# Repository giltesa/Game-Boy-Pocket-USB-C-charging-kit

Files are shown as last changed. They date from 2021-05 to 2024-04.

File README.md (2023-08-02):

# Game Boy Pocket USB-C Charging Kit

( This project is a fork from my Game Boy Color USB-C Charging Kit )

The **Game Boy Pocket USB-C Charging Kit** is a circuit that allows you to charge a **Nintendo Game Boy Pocket** by **USB-C** and use a **Li-ion** battery instead of AA batteries.

This circuit includes the famous **TP4056** and **DW01A**. The first one is the device in charge of charging the battery, and the second one is protecting the lifetime of the battery of the over-discharge.

This kit includes two boards. If you want to install it easy, it's enough with the main board which doesn't need any cable for working. However, if you want to have the status LEDs in the same place as the original status LED, then you will need to solder the second board and joint both with 3 cables. You can choose the best option for you.

This kit contains 3 boards:

- USB-C board
- Main board
- LEDs board

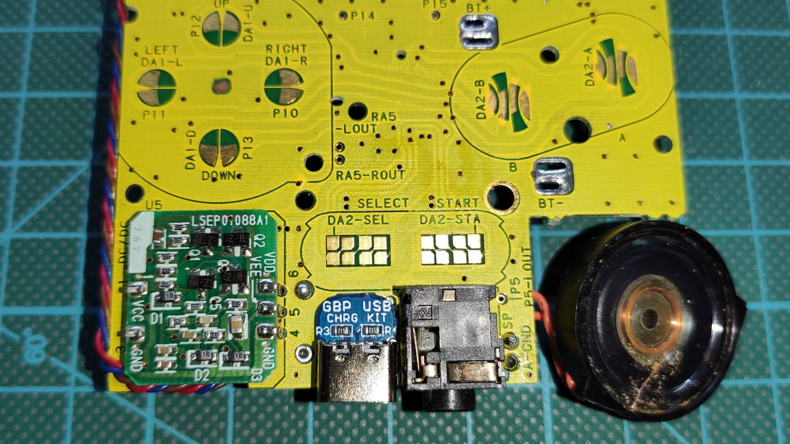
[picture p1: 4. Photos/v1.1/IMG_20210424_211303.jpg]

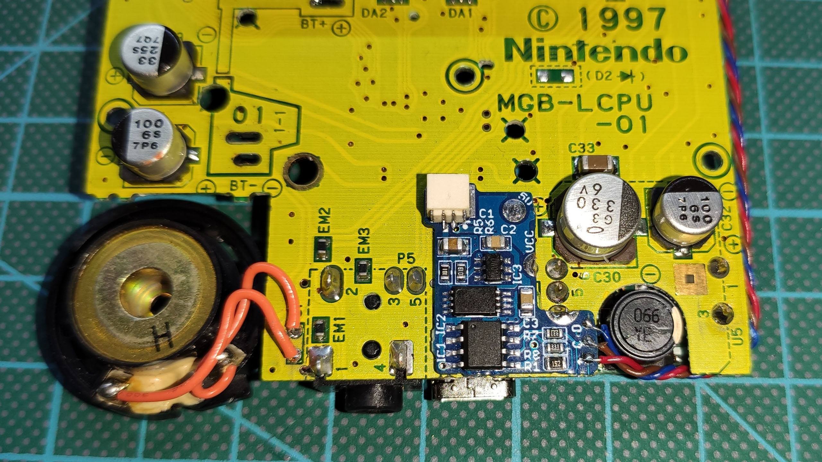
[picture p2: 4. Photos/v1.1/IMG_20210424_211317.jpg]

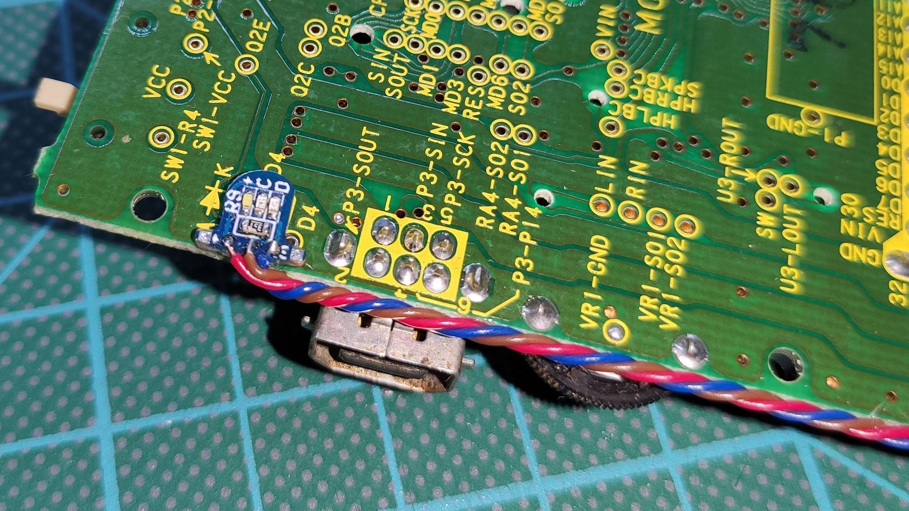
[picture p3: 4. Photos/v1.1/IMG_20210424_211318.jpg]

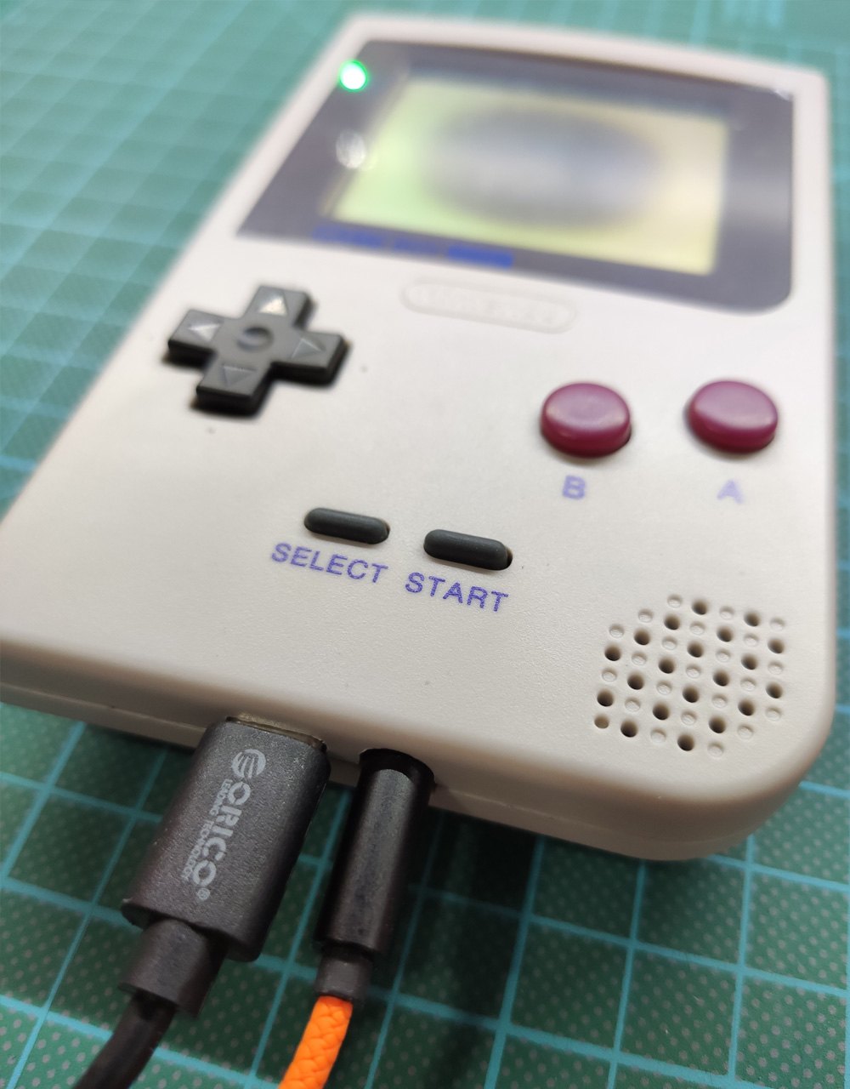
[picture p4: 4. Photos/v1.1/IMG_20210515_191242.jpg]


## Youtube:

Game Boy Pocket USB-C Charging Kit (Installation)

GBP (https://www.youtube.com/watch?v=yOIhhSY7Itc)

## Would you like it?

https://shop.giltesa.com/product/game-boy-pocket-usb-c-charging-kit/

## More

- [giltesa.com](https://giltesa.com "giltesa.com")
- [twitter.com](https://twitter.com/giltesa "twitter.com")

## License

This project is licensed under a **Creative Commons** license:
**[Attribution-NonCommercial-ShareAlike 4.0 International (CC BY-NC-SA 4.0) ](https://creativecommons.org/licenses/by-nc-sa/4.0/)**

Check the [LICENSE.md](LICENSE.md) for more information.

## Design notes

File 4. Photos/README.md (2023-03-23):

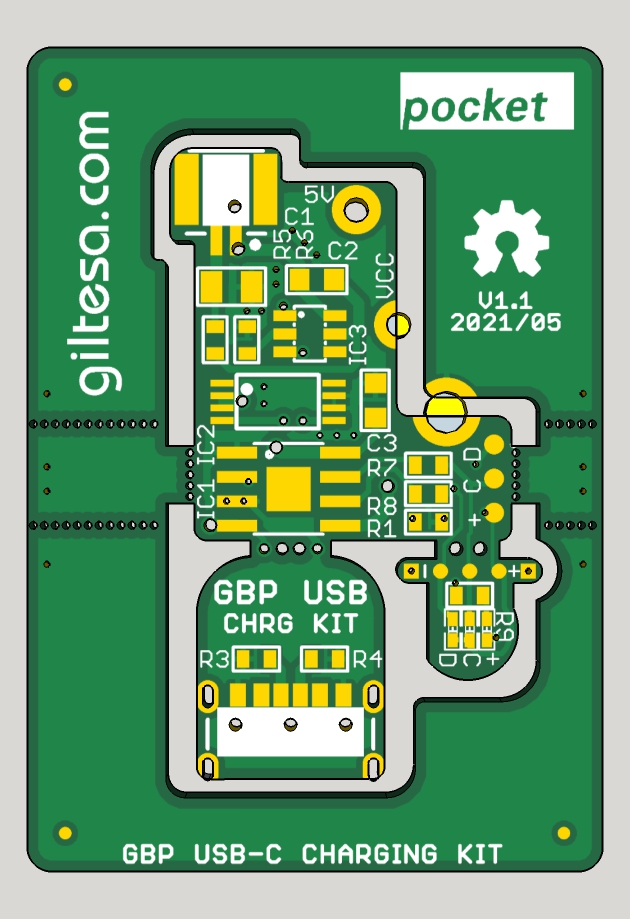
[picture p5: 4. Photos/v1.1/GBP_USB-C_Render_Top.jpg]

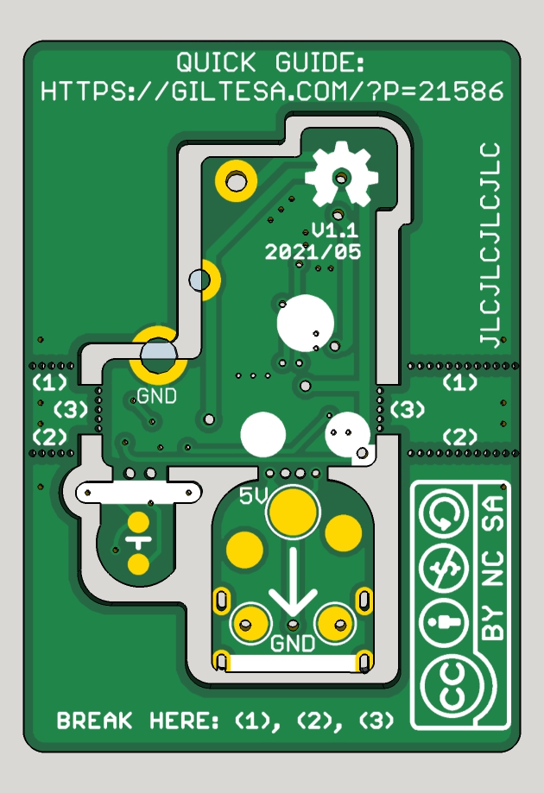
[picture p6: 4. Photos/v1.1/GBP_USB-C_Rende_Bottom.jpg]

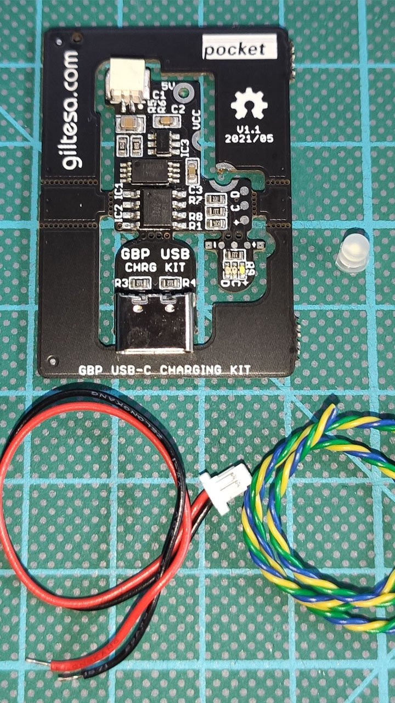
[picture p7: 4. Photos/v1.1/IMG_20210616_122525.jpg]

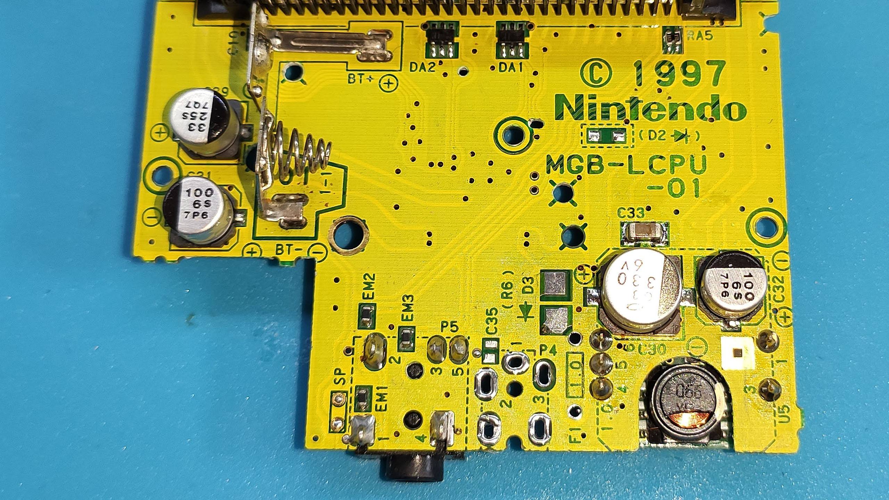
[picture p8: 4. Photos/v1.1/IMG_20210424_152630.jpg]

GBP
GBP
GBP
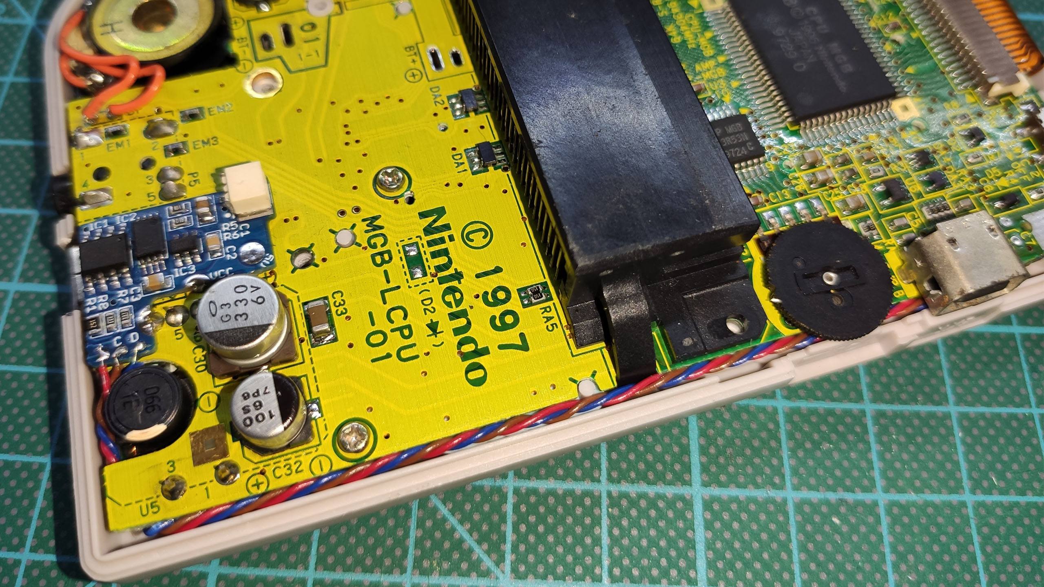
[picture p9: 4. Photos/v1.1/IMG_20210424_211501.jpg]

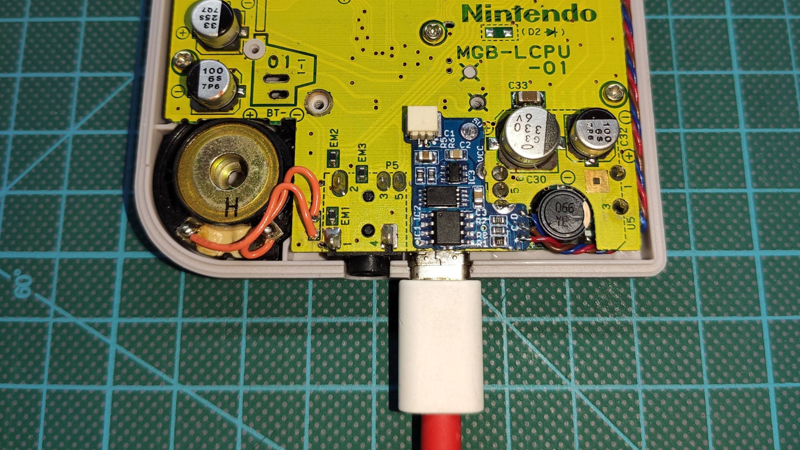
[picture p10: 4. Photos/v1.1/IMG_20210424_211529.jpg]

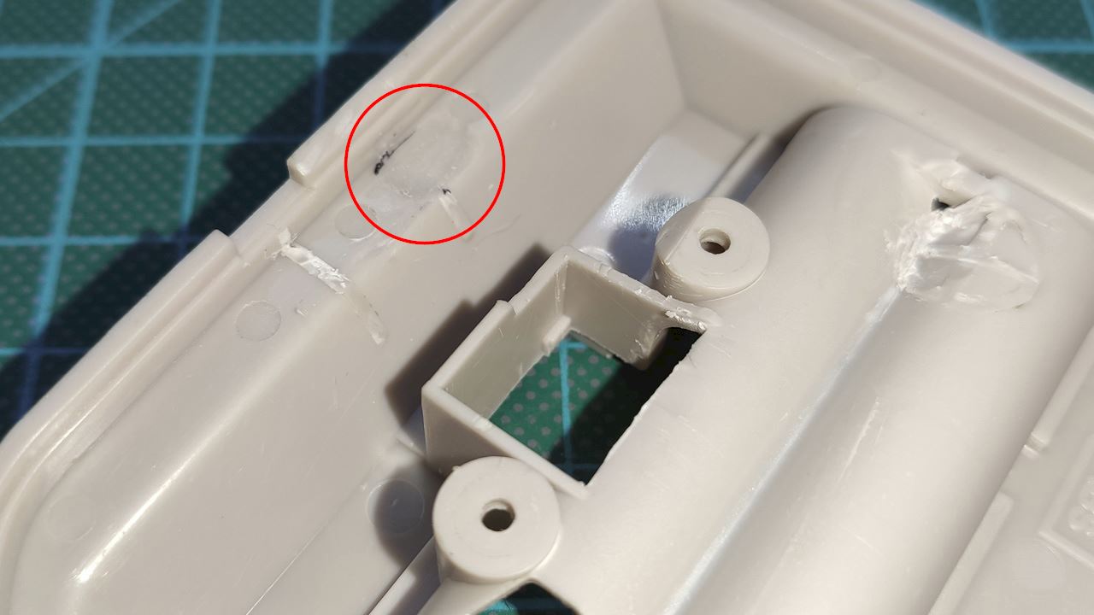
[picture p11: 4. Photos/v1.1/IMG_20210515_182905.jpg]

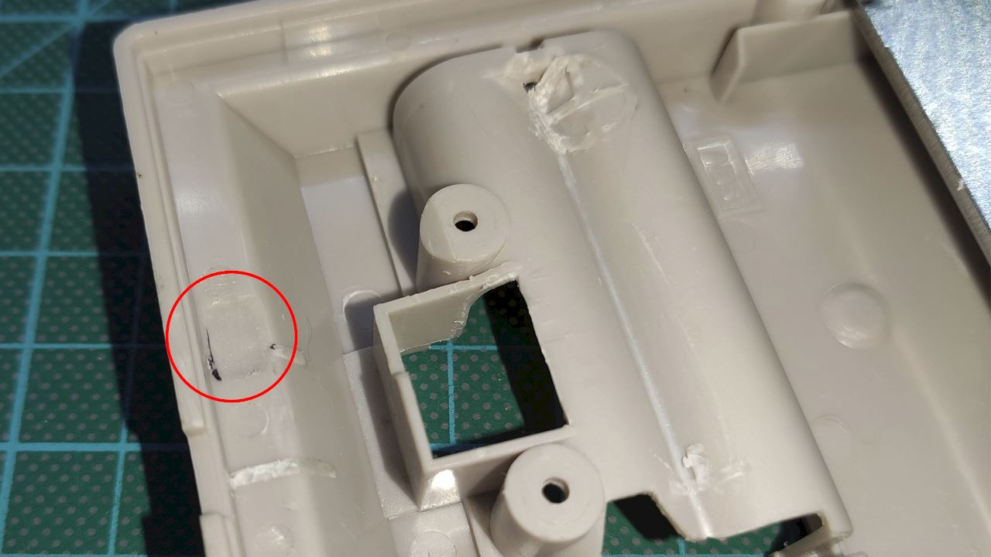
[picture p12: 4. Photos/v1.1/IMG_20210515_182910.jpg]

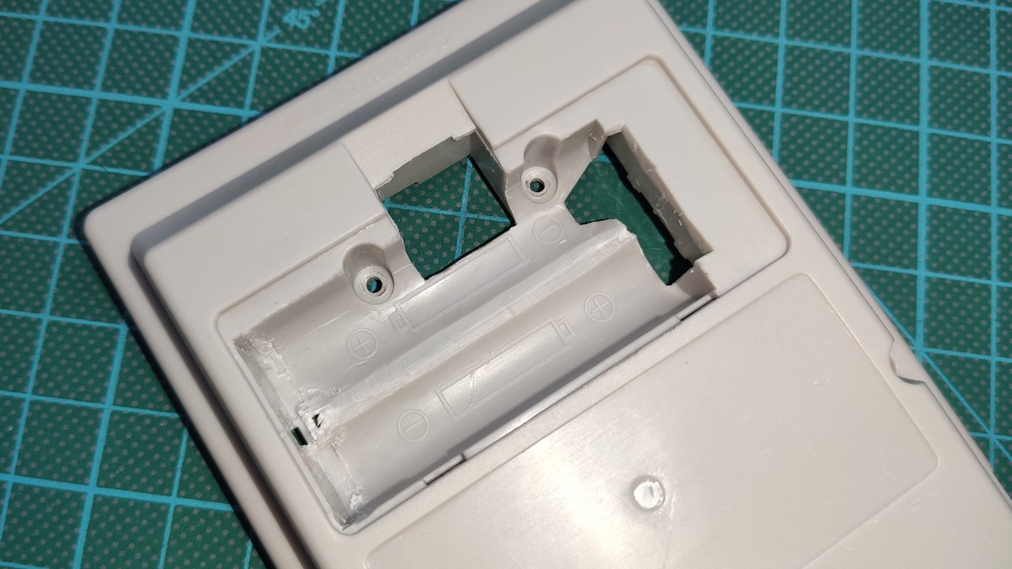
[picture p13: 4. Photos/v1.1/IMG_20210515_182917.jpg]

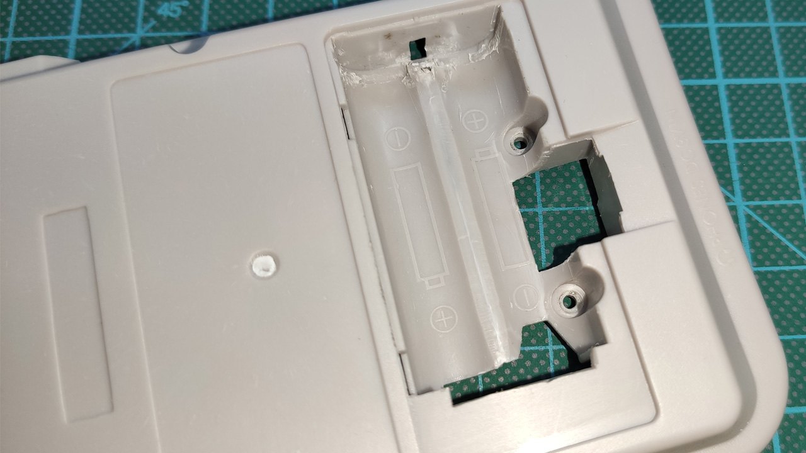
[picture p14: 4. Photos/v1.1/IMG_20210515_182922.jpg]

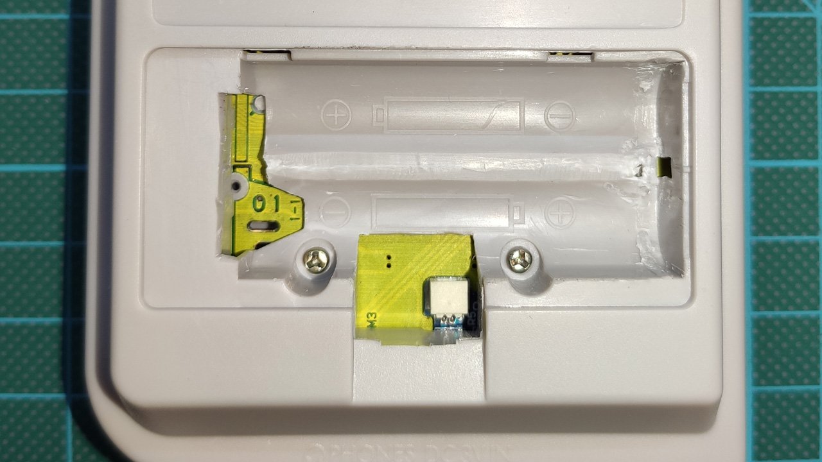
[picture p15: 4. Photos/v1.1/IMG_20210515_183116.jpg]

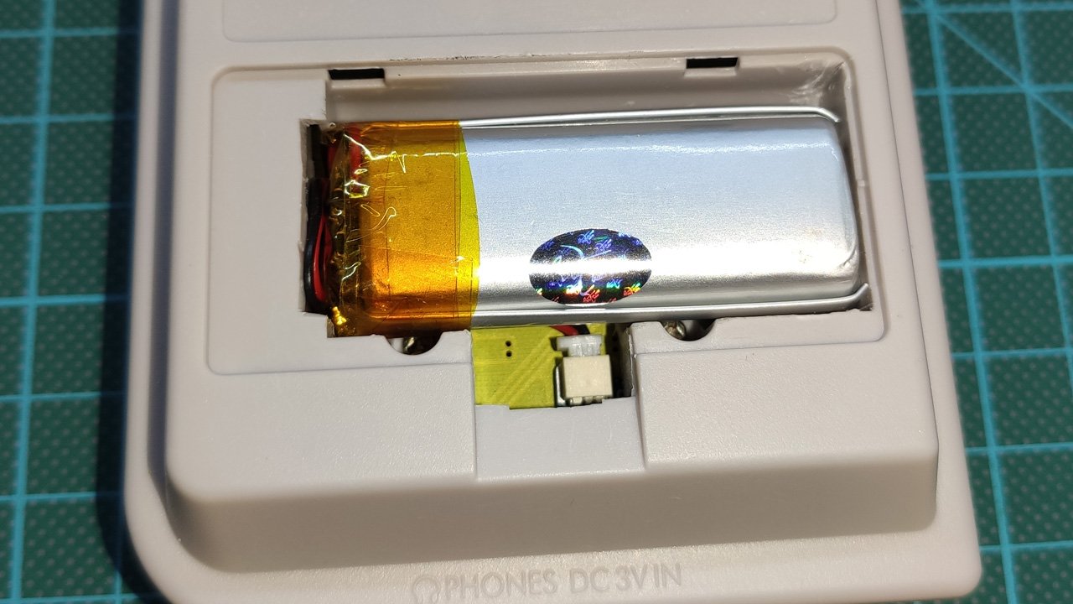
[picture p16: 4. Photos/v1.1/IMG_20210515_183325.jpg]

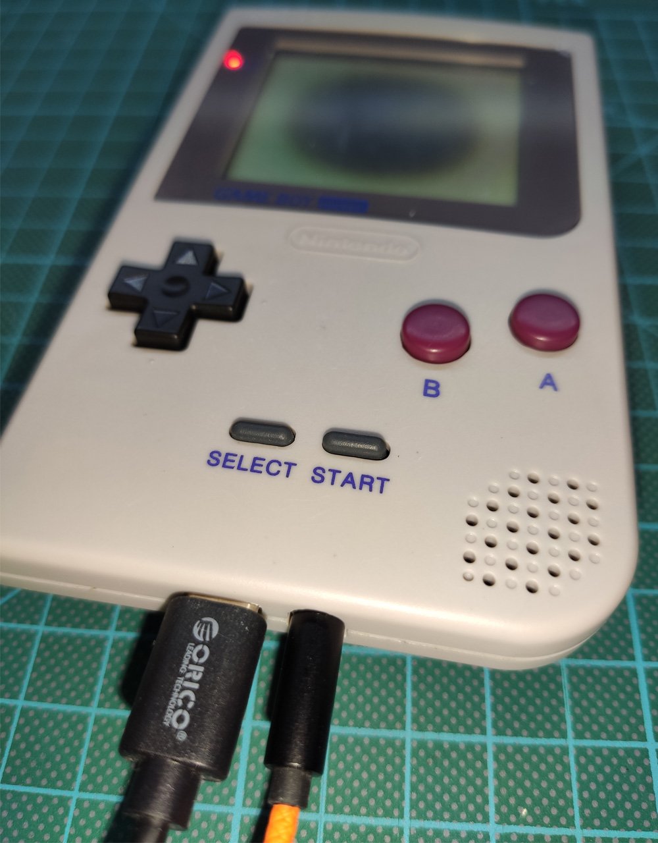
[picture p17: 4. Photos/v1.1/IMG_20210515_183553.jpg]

GBP

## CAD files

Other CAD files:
2. Renders, 3D models/GBP USB-C Charging Kit v1.2 frame.skp
2. Renders, 3D models/GBP USB-C Charging Kit v1.2.skp
2. Renders, 3D models/GBP USB-C Charging Kit v1.3.skp
2. Renders, 3D models/GBP USB-C Charging Kit v2.0 - Black.skp

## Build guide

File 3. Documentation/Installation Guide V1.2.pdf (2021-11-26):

# USB-C CHARGING KIT FOR GAME BOY POCKET

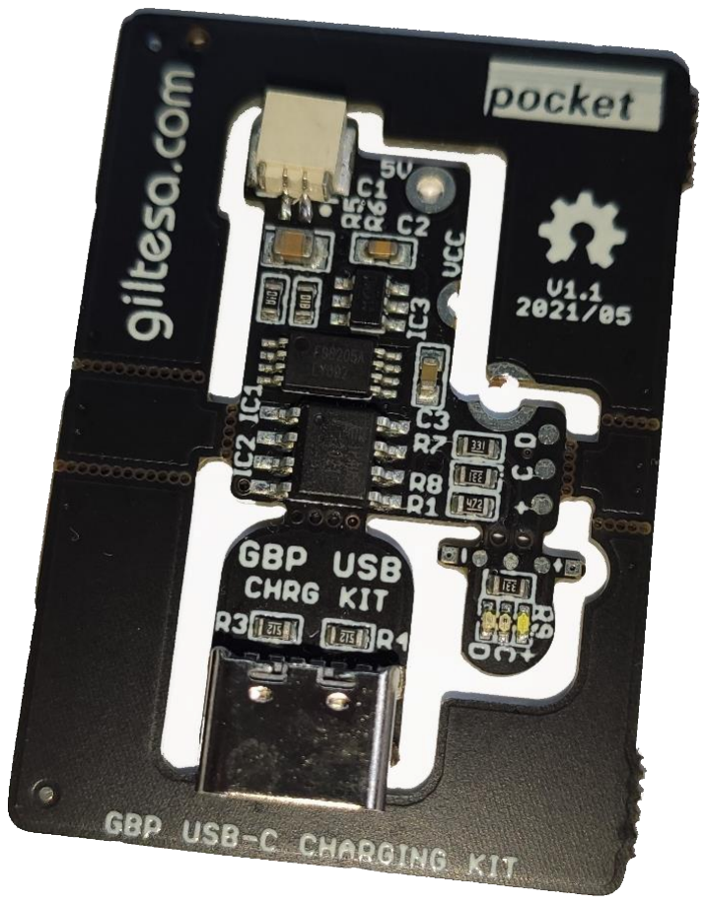
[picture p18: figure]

# VIDEO INSTALLATION

https://www.youtube.com/watch?v=yOIhhSY7Itc

# NINTENDO USB-C CHARGING KITS

https://giltesa.com/en/nintendo-usb-c-charging-kit

The Game Boy Pocket USB-C charging kit is a circuit that allows you to charge a Nintendo Game Boy Pocket by USB-C and use a Li-ion battery instead of AAA batteries.

This circuit includes the famous TP4056 and DW01A. The first one is the device in charge of charging the battery, and the second one is protecting the lifetime of the battery of the overdischarge.

Because the GBP board doesn’t have enough free space, you need to remove some components of your GBP board before the installation. These components are not necessary because this board replaces the AAA and jack powered.

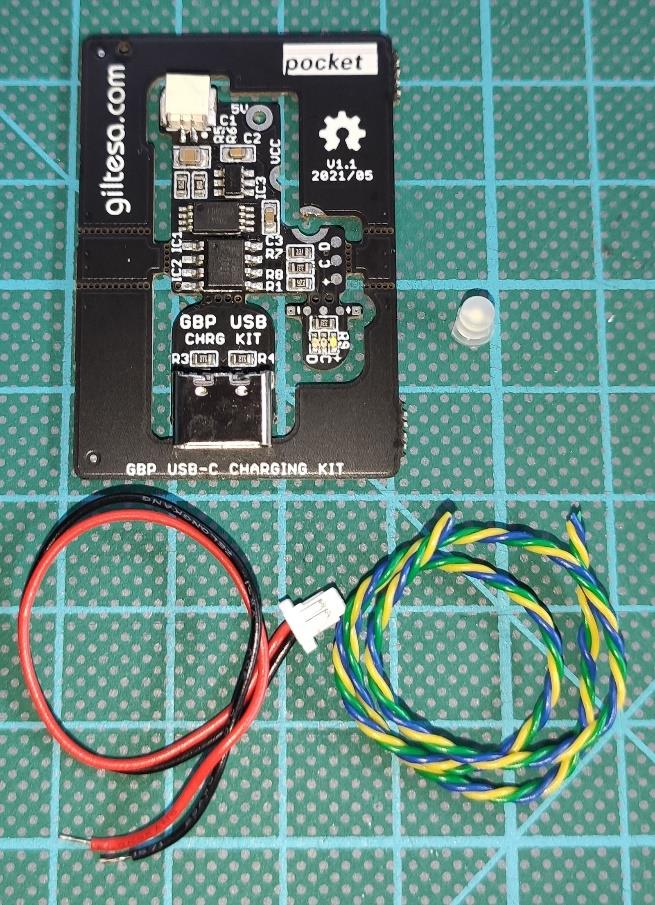
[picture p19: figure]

Included with this kit:

- Main board + USB-C board + LEDs board
- Light diffuser
- Li-ion battery cable
- Installation cable

Not included:

- Li-ion battery

Required tools:

- Screwdriver: + and Y
- Soldering iron
- Tin
- Flux
- Isopropyl alcohol
- Tweezers
- Cutter for cutting the case

This module has been designed to be used with the console's original voltage regulator because it supports an input voltage range between 2 a 4.6V and the battery kit provide a voltage between 2.75 a 4.2V. If you also want to change the original power supply, it’s important it is compatible with the voltage provided for the battery kit, otherwise you may damage something.

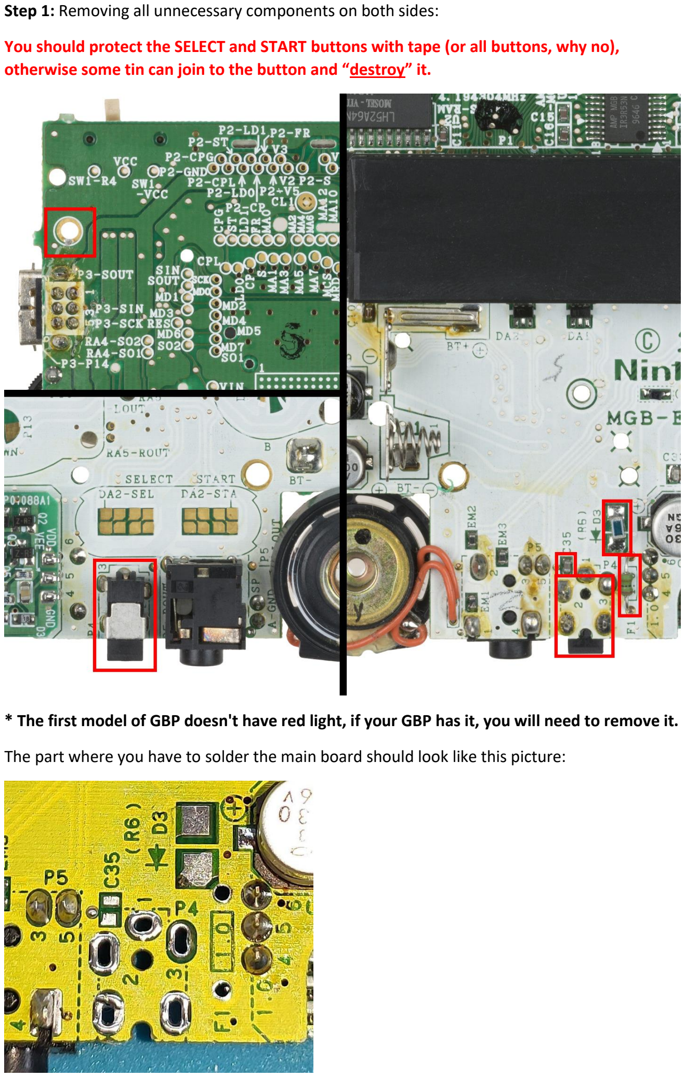
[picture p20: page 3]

Step 1: Removing all unnecessary components on both sides:

You should protect the SELECT and START buttons with tape (or all buttons, why no), otherwise some tin can join to the button and “destroy” it.

* The first model of GBP doesn't have red light, if your GBP has it, you will need to remove it.

The part where you have to solder the main board should look like this picture:

Step 2: The USB-C board must be the first board you have to solder. It is because the pads to solder it are in the opposite side of the jack and after you have finished to solder it the next board, main board, will hide the pads.

For soldering it, I recommend you pre-solder first the VCC pad and then, solder it to the GBP board and if you have centred it well, you can continue with the rest of the pads to hold it super strong.

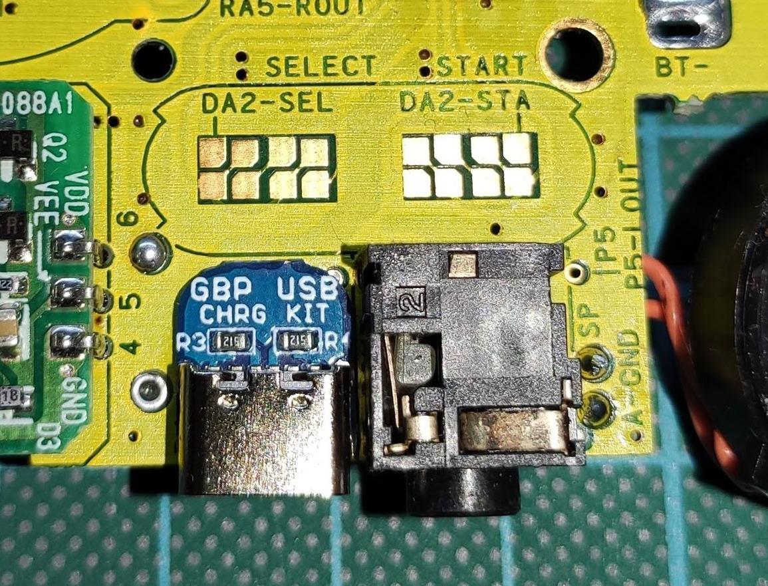
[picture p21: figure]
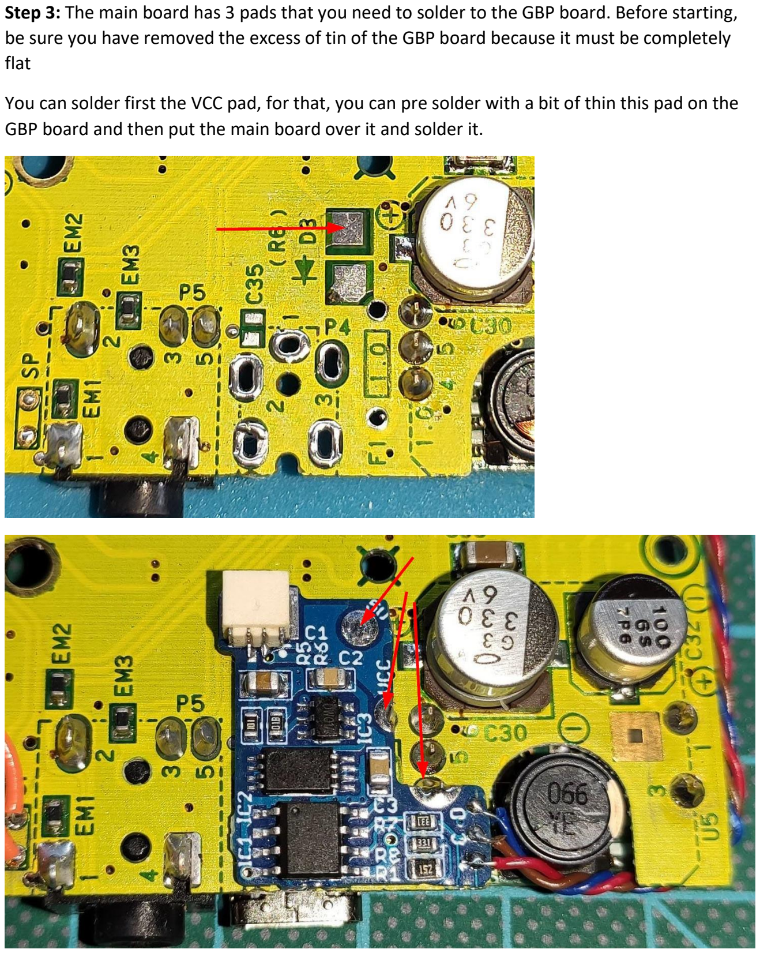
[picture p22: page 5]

Step 3: The main board has 3 pads that you need to solder to the GBP board. Before starting, be sure you have removed the excess of tin of the GBP board because it must be completely flat

You can solder first the VCC pad, for that, you can pre solder with a bit of thin this pad on the GBP board and then put the main board over it and solder it.

Step 4: Soldering the LEDs board. This board is as small as the original LED. This board has 2 pads on the bottom side and 5 more on the top side.

There are two possible ways to solder it, but one part is common:

Only for GBP with red light:

After removing the original red light, you can see two pads under where the LED was. You have to solder these two pads to the two pads on the bottom side of the light board.

You can pre-solder the pads on the bottom side of the light board and then, put the board in the correct place and hot the opposite side of the GBP board. You will see how the tin start to melt and join.

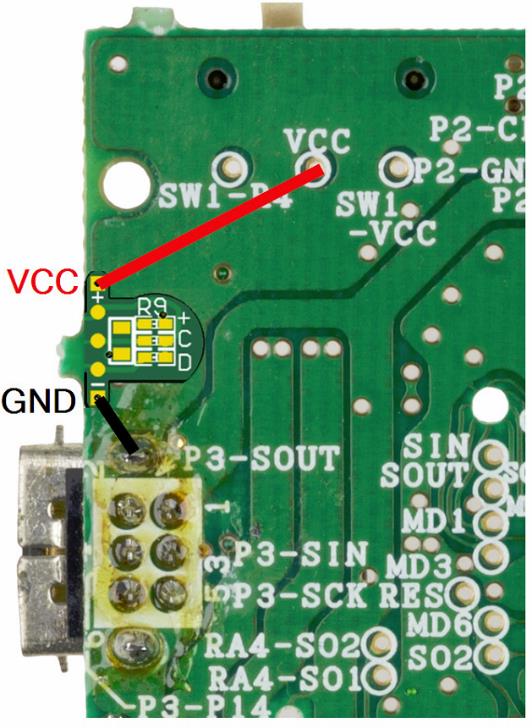
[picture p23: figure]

Only for GBP without red light:

Because this model doesn’t have light, you can install the light board in the same place as others GBP models.

First, you should put a bit of tape to protect the GBP and light board of short circuit. Put the tape on the big hole next to the EXT connector. You can use double side tape and use it to hold the light board to the GBP board.

After that, you can solder these two pins to the alternative points for getting these light indicator feature.

Common part:

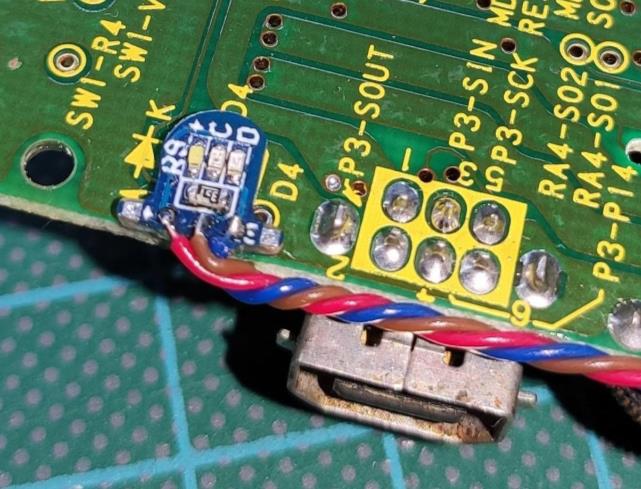
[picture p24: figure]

You can see the light board has 5 pads on the top side. You will need to solder the 3 pads in the centre to the main board.

Be sure, you join the pads with the correct pad of the main board.

- + to + (VCC)
- C to C (CHARGE)
- D to D (DONE)

## Extra information

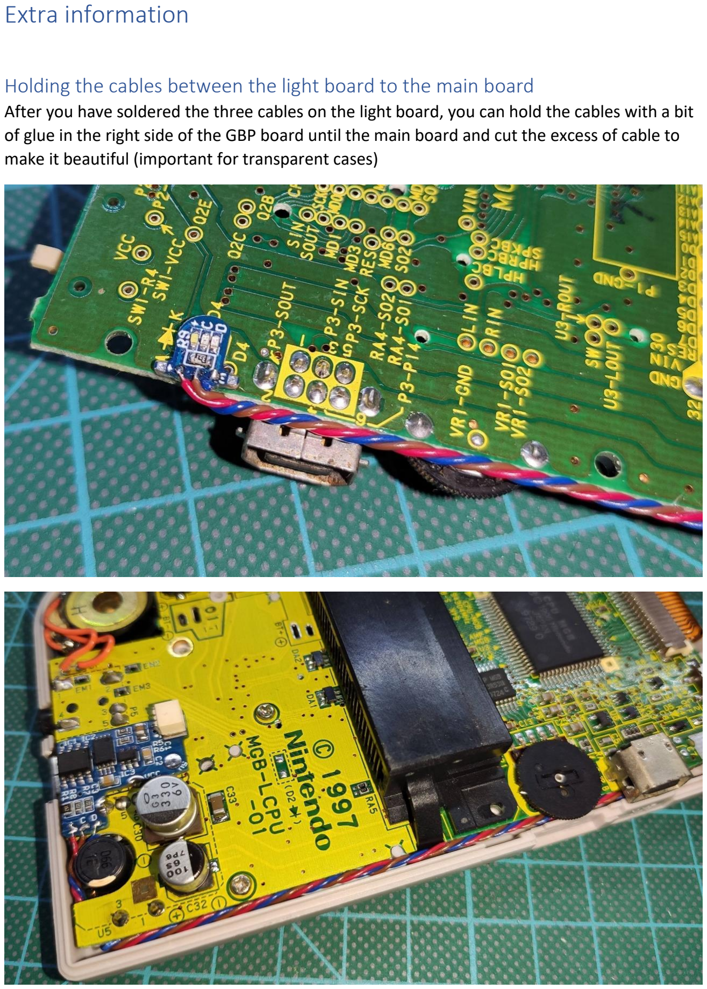
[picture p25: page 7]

### Holding the cables between the light board to the main board

After you have soldered the three cables on the light board, you can hold the cables with a bit of glue in the right side of the GBP board until the main board and cut the excess of cable to make it beautiful (important for transparent cases)

### LED diffuser

The kit includes a LED diffuser. It is a simple 3mm LED without legs that help the light board to focus the light to the centre.

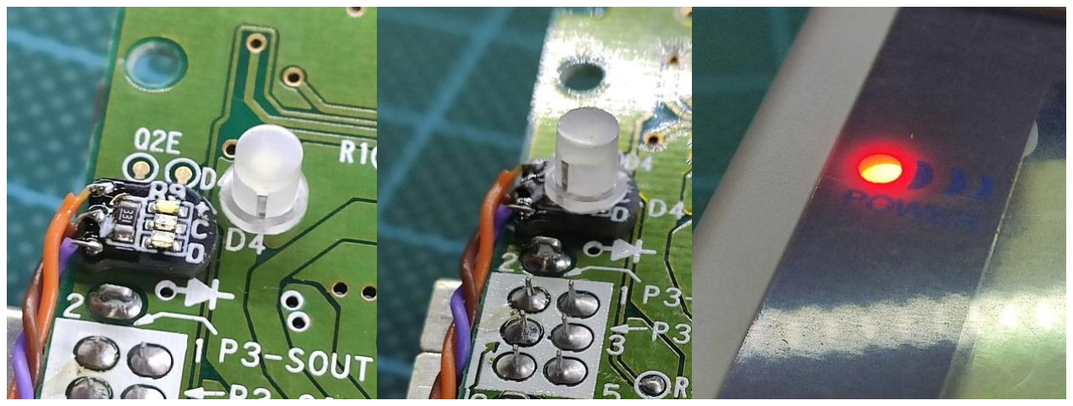
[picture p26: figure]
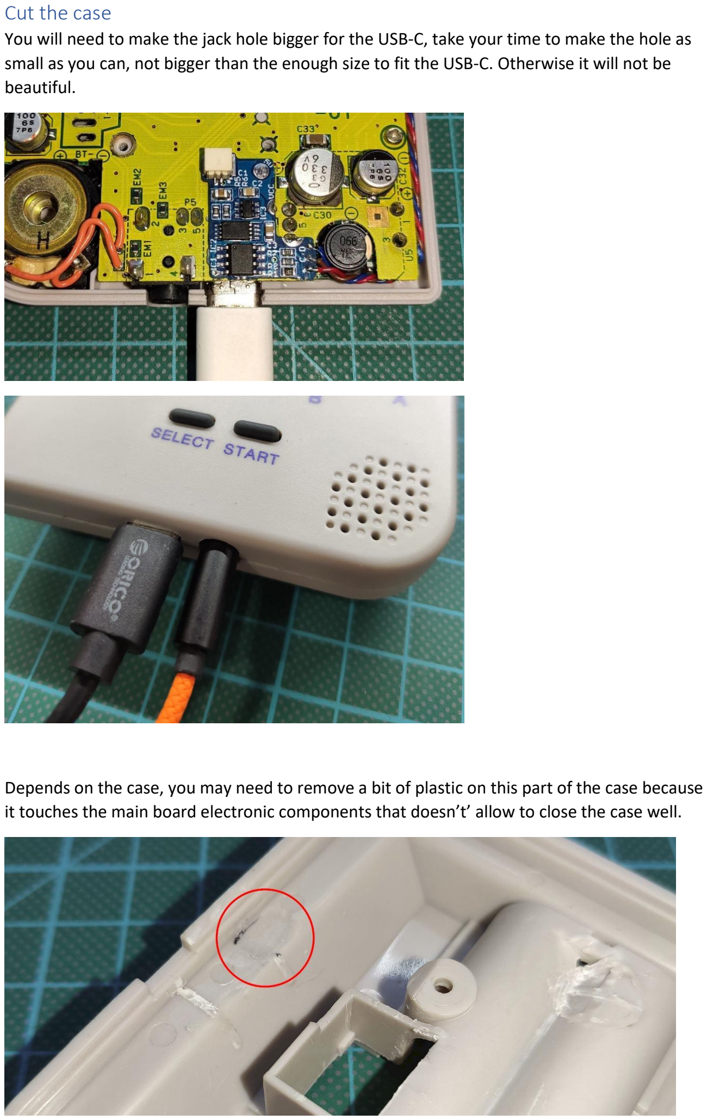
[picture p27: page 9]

### Cut the case

You will need to make the jack hole bigger for the USB-C, take your time to make the hole as small as you can, not bigger than the enough size to fit the USB-C. Otherwise it will not be beautiful.

Depends on the case, you may need to remove a bit of plastic on this part of the case because it touches the main board electronic components that doesn’t’ allow to close the case well.

### Battery

You can put the battery as big as you can find, in my case cutting the case as you can see in these pictures, I was able to put a 1500mAh battery.

Inside the documentation folder on the GitHub you can find information about the battery:

https://github.com/giltesa/Game-Boy-Pocket-USB-C-chargingkit/tree/master/3.%20Documentation/Battery (https://github.com/giltesa/Game-Boy-Pocket-USB-C-charging-kit/tree/master/3.%20Documentation/Battery)

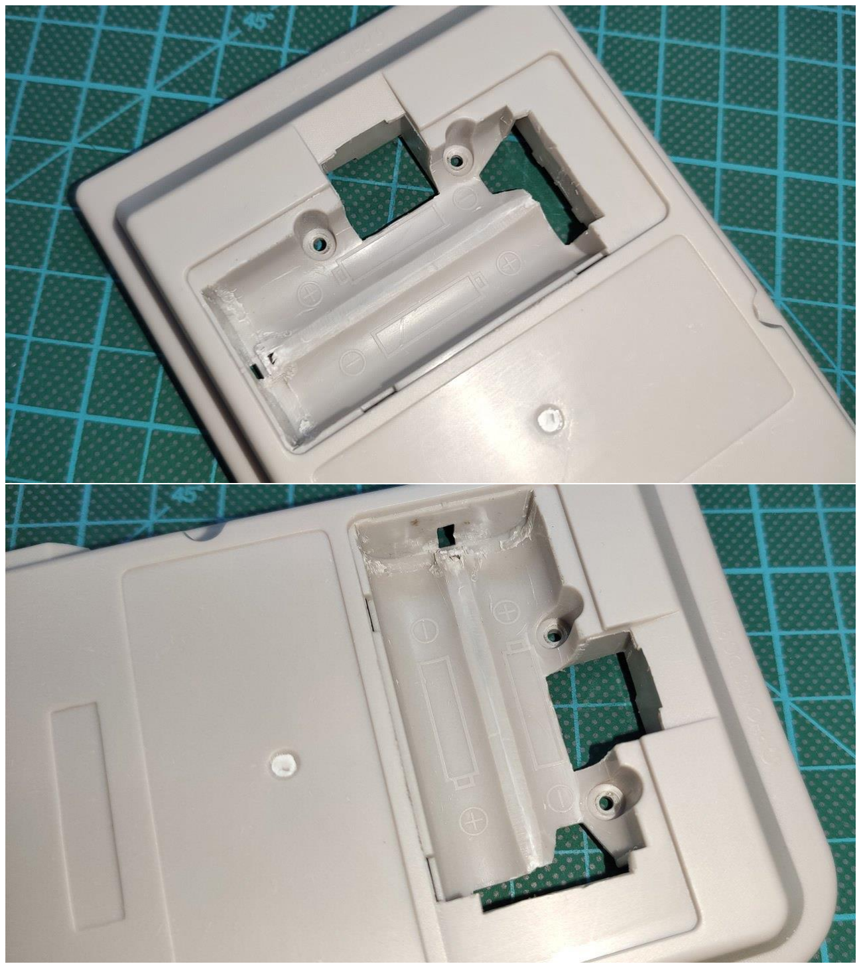
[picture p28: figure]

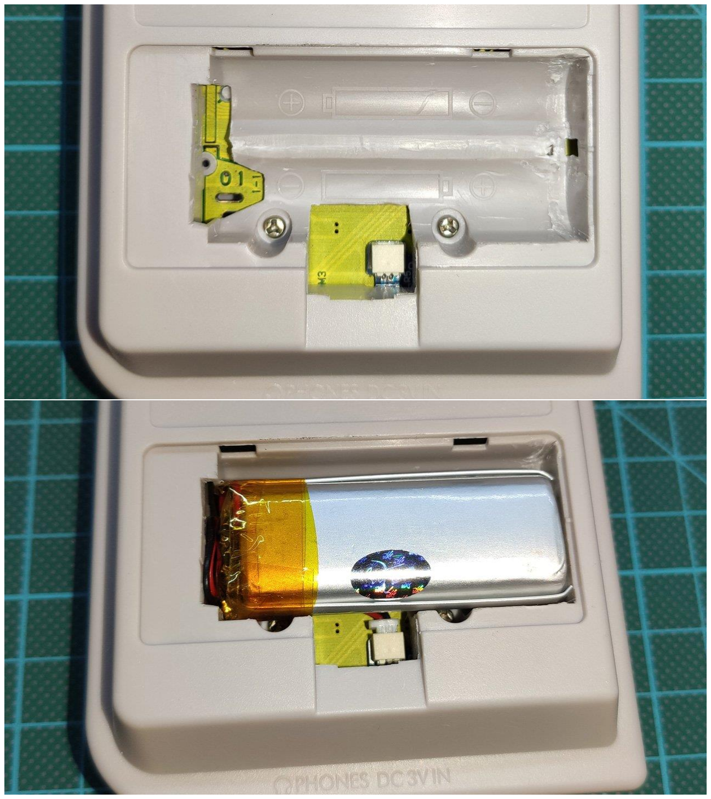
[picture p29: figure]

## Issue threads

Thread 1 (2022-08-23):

help with MGB-CPU-01 instructions

aparrish, 2022-08-23:
Hi! I'm trying to install the mod on a MGB-CPU-01 board. The [instructions in the Documentation directory](https://github.com/giltesa/Game-Boy-Pocket-USB-C-charging-kit/blob/master/3.%20Documentation/Incompatibility%20MGB-CPU-01.pdf) are a bit unclear to me. Could you maybe rephrase or rewrite the instructions? As currently written, it seems to me as though steps 1 and 2 are contradictory. Step 1 says to cover both pads with kapton tape, but then step 2 says that you should solder one of the pads... which would be covered with kapton tape at that point, if you followed step 1.

It seems like what I should be doing is soldering a bodge wire from the upper pad of D2 to pin 1 of the DC jack connector, and then covering the lower pad of D2 with kapton tape, along with the bodge wire, but leaving the upper pad of D2 exposed. Is that the case, or is it something else?

giltesa, 2022-08-24:
Hello Allison,

Sorry, yes, it was a bit confusing. I updated the pdf, I hope it is easier
to understand now:
https://github.com/giltesa/Game-Boy-Pocket-USB-C-charging-kit/blob/master/3.%20Documentation/Incompatibility%20MGB-CPU-01.pdf

[image: imagen.png]

Kind regards,
Alberto

El mié, 24 ago 2022 a las 1:54, Allison Parrish ***@***.***>)
escribió:

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

aparrish, 2022-08-24:
Ah okay, I get it! So the goal is to connect the 5V pad on the USB-C board to pin 1 of the DC jack, and to make sure that nothing gets accidentally soldered to either of the D2 pads. Thanks!

Closed 2022-08-24.

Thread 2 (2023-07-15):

biggest battery possible?

szechp, 2023-07-15:
Not an issue but a question:

If I cut down my shell to completely remove the battery compartments plastic, what's the biggest battery I can fit in there? I wouldnt mind if the battery is on the PCB, with only some tape between them.

giltesa, 2023-07-15:
Hello Philipp,

I was able to install a [1500mAh ](https://www.aliexpress.com/item/4000036271843.html) battery in a not trimmed battery compartment. If the compartment is ready for li-ion batteries, then it's possible to install a [1800mAh](https://www.aliexpress.com/item/1005001308043027.html) battery.

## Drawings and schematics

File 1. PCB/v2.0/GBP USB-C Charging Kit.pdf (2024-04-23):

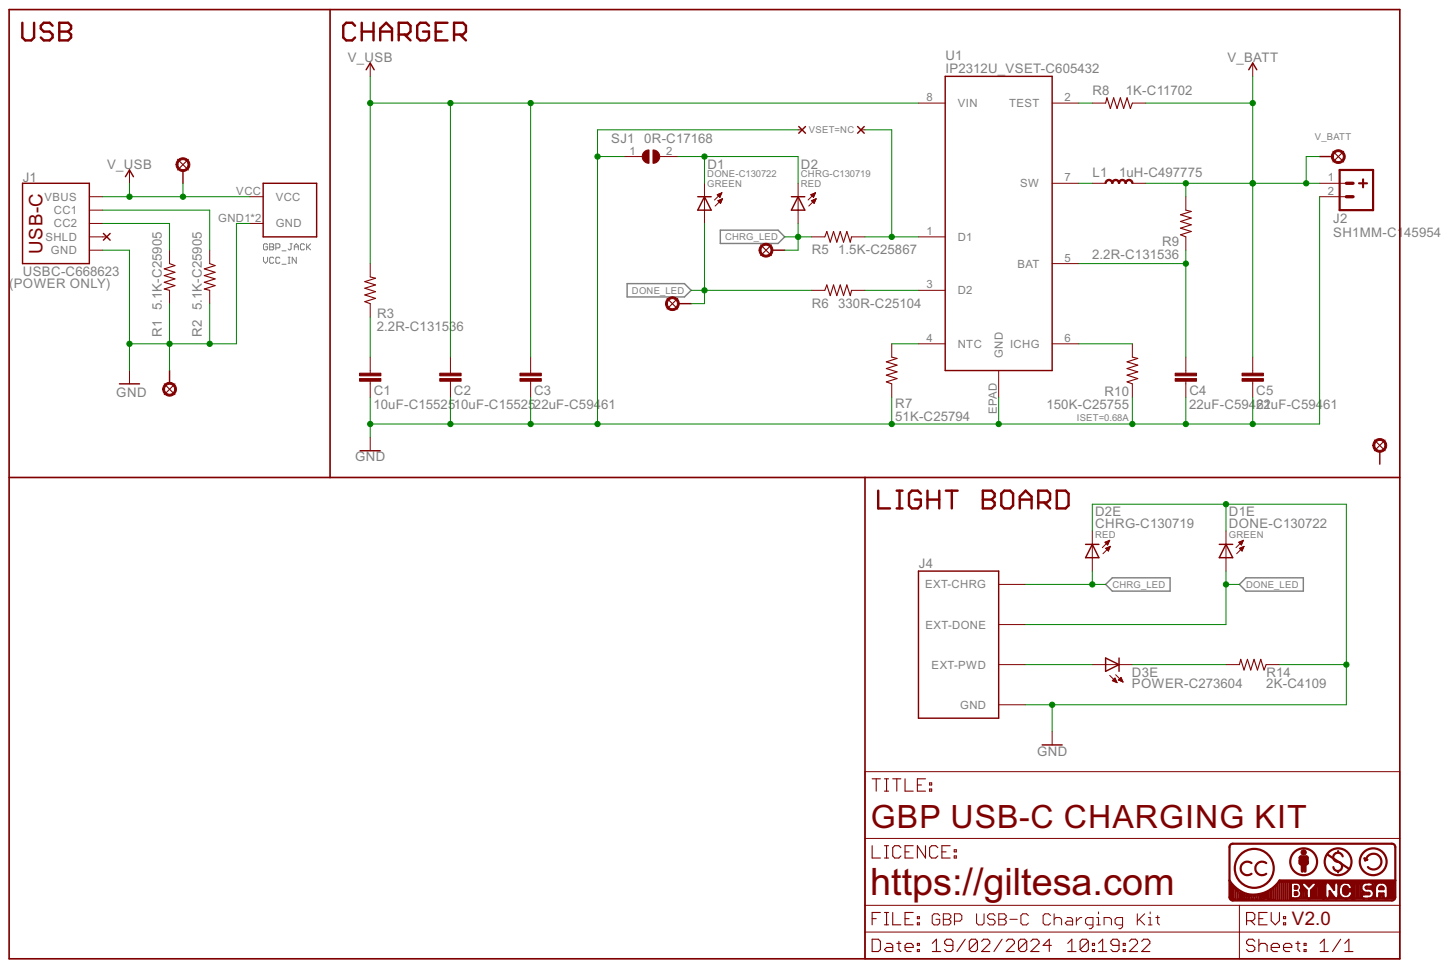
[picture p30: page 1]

GBP USB-C CHARGING KIT
https://giltesa.com

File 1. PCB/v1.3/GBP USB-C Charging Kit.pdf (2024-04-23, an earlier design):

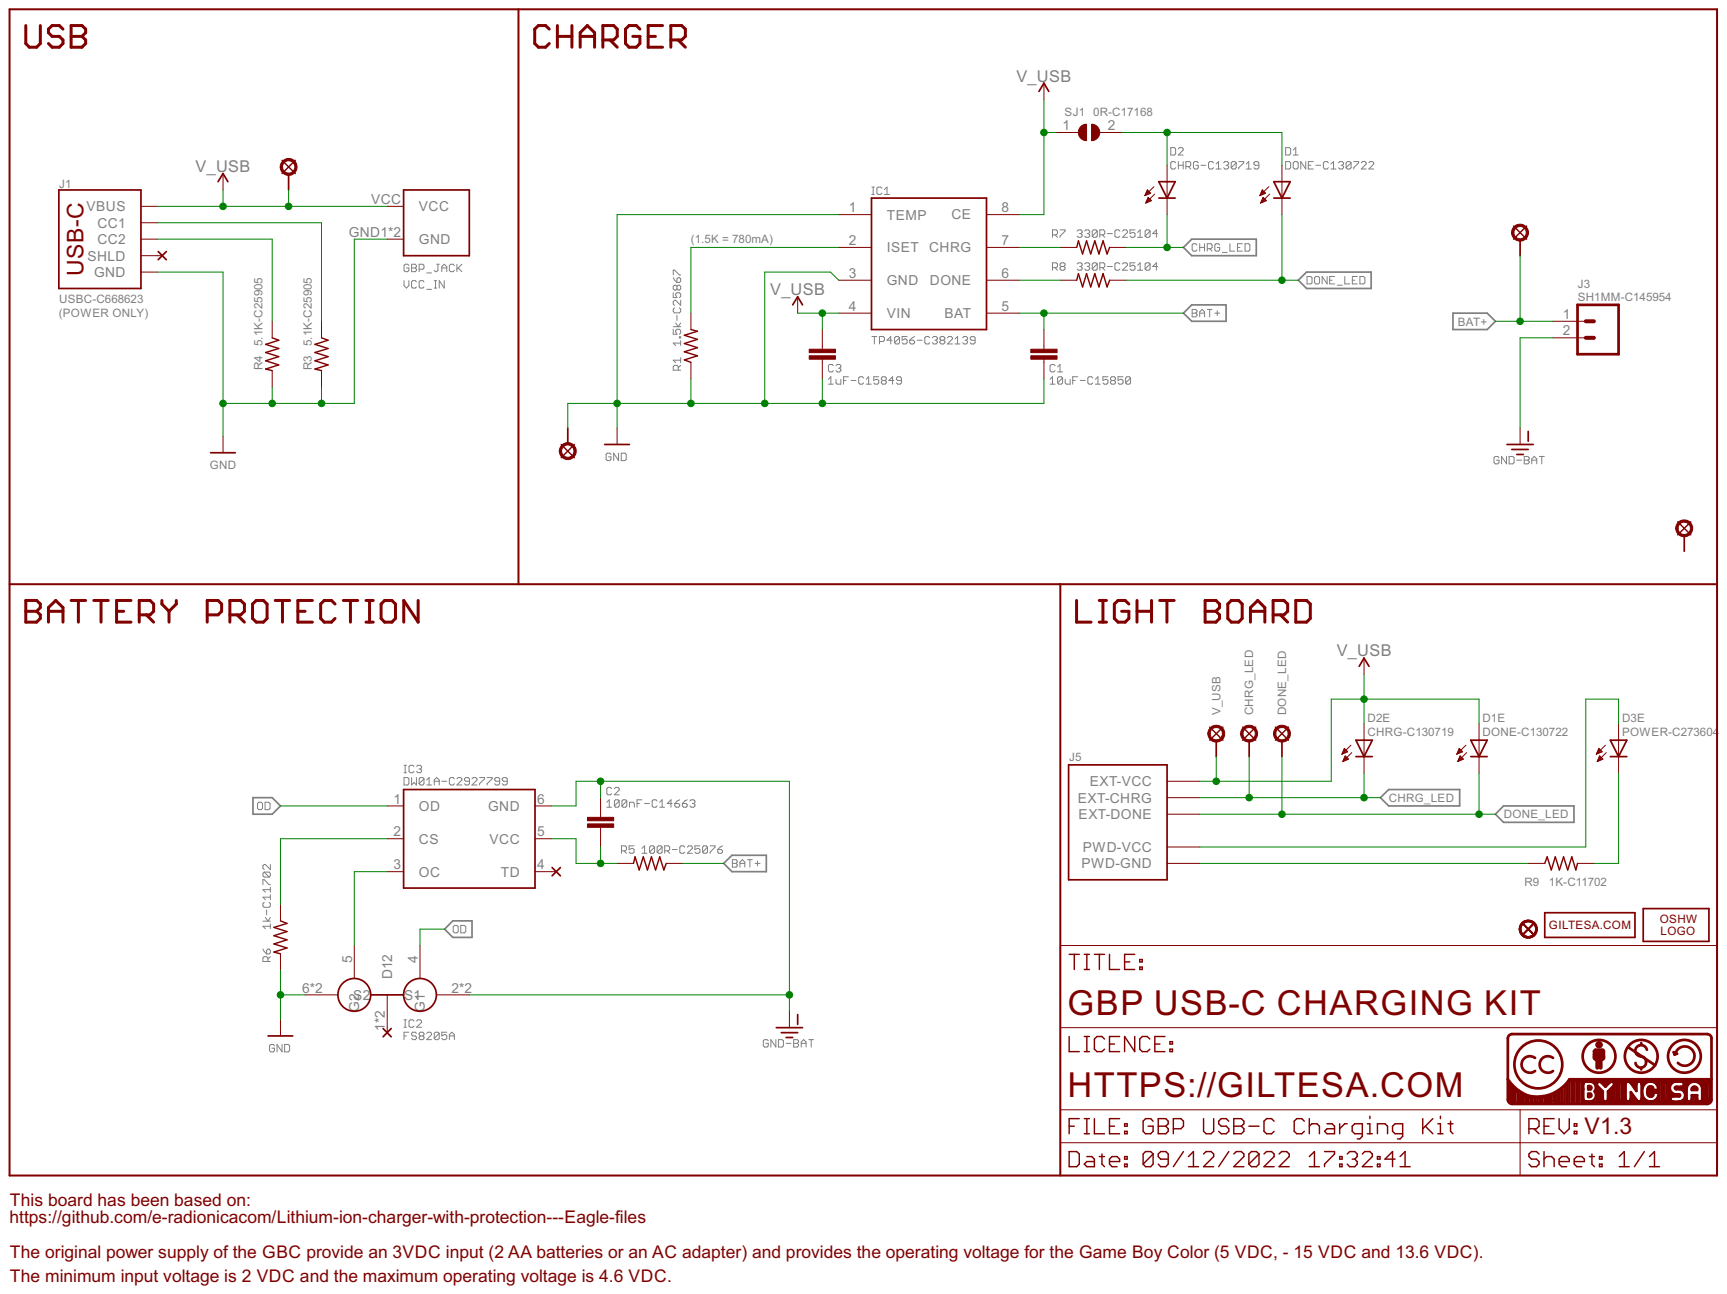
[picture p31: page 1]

GBP USB-C CHARGING KIT

https://github.com/e-radionicacom/Lithium-ion-charger-with-protection---Eagle-files This board has been based on: The original power supply of the GBC provide an 3VDC input (2 AA batteries or an AC adapter) and provides the operating voltage for the Game Boy Color (5 VDC, - 15 VDC and 13.6 VDC). The minimum input voltage is 2 VDC and the maximum operating voltage is 4.6 VDC.

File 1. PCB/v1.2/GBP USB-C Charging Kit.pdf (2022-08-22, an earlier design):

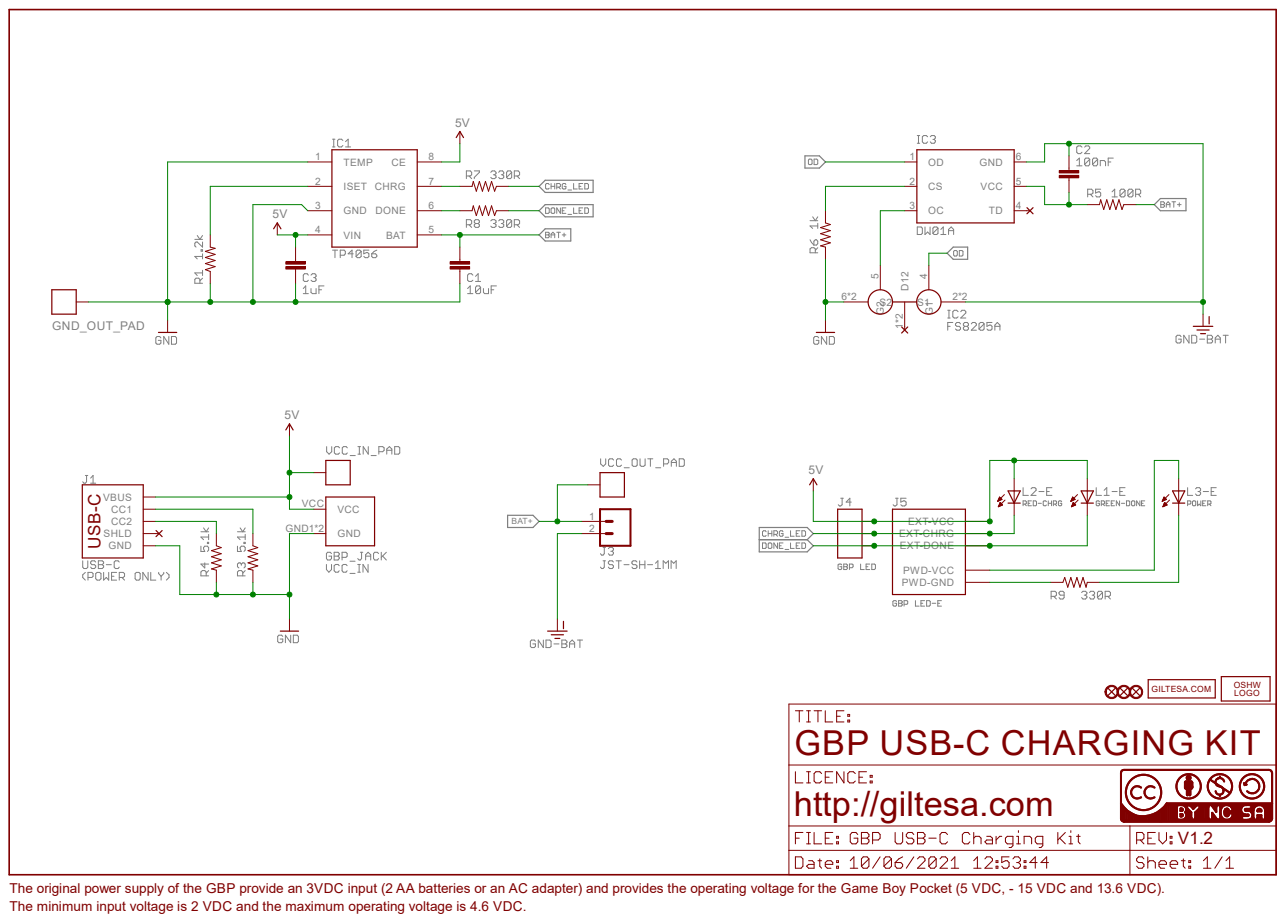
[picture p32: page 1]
TEMP 1; ISET 2; GND 3; VIN 4; BAT; DONE; CHRG; VCC; GND; VBUS CC1 CC2 SHLD; PWD-GND; PWD-VCC; EXT-CHRG EXT-DONE; EXT-VCC 1 2 GND GND1*2; VCC VCC GND_OUT_PAD; BAT+; GBP USB-C CHARGING KIT; OSHW

The minimum input voltage is 2 VDC and the maximum operating voltage is 4.6 VDC. USB⁻C

LOGO GILTESA.COM

http://giltesa.com

The original power supply of the GBP provide an 3VDC input (2 AA batteries or an AC adapter) and provides the operating voltage for the Game Boy Pocket (5 VDC, - 15 VDC and 13.6 VDC).

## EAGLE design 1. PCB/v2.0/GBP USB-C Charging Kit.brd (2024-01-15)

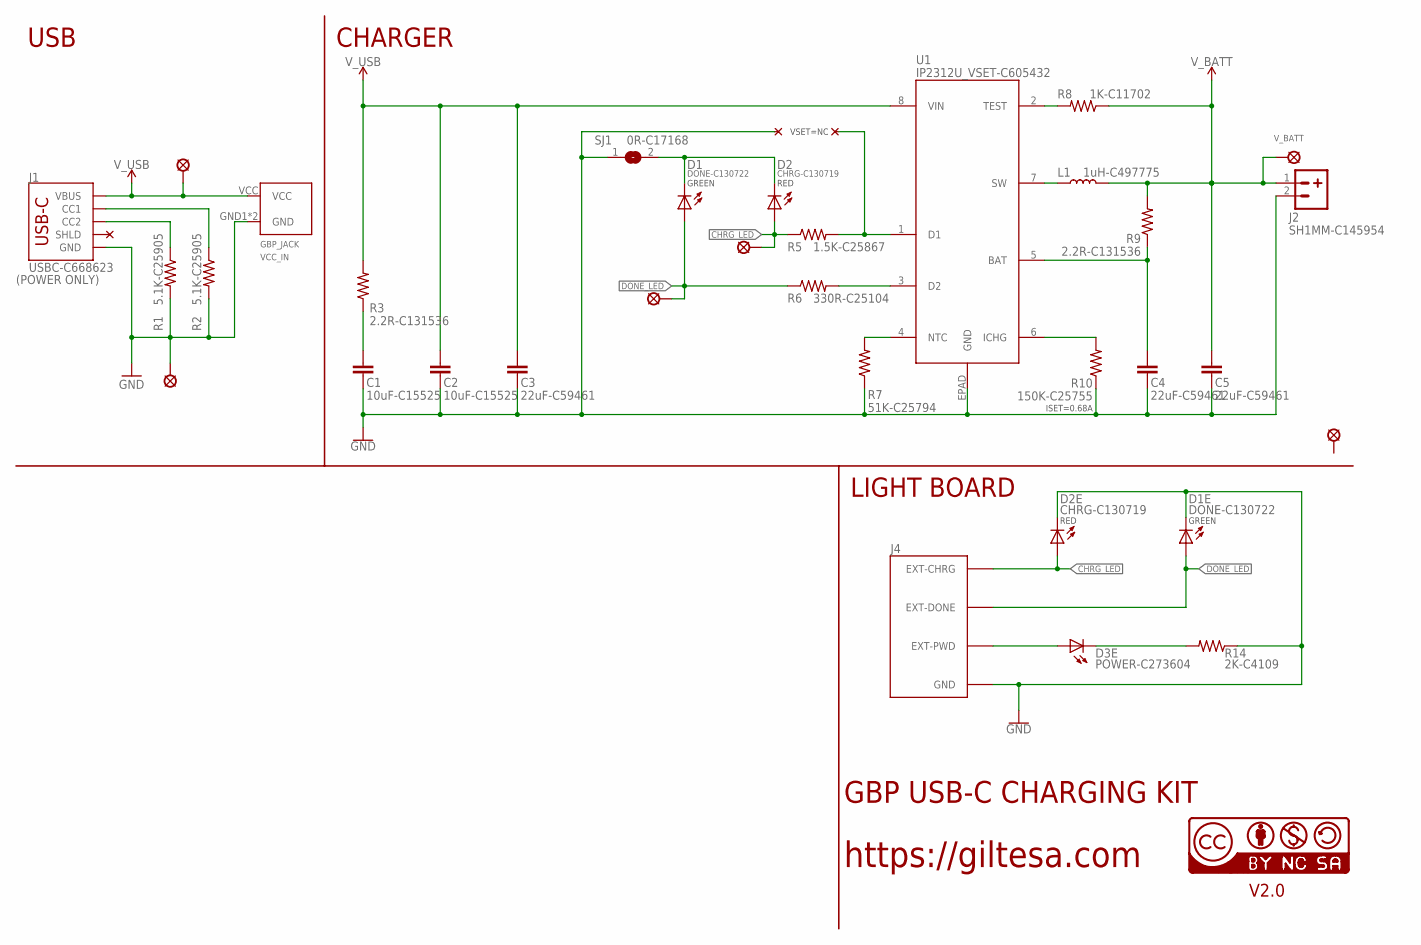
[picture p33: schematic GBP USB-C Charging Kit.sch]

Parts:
C1, C2: 10uF-C15525; C0402_S
C3, C4, C5: 22uF-C59461; C0603_S
D1, D1E: DONE-C130722; L0402
D2, D2E: CHRG-C130719; L0402
D3E: POWER-C273604; L0402
GBP_JACK: VCC_IN; GBP_POWER_JACK_DIP
J1: USBC-C668623; USB-C_6P
J2: SH1MM-C145954; JST-2-1MM-SMD_RIGHT
J4: GBP_LED_V2
L1: 1uH-C497775; PSPMAA0402
R1, R2: 5.1K-C25905; R0402
R3, R9: 2.2R-C131536; R0402
R5: 1.5K-C25867; R0402
R6: 330R-C25104; R0402
R7: 51K-C25794; R0402
R8: 1K-C11702; R0402
R10: 150K-C25755; R0402
R14: 2K-C4109; R0402
SJ1: 0R-C17168; JUMPER-SMD_0402
U1: IP2312U_VSET-C605432; IP2312
U$1: V_BATT; PAD_1.25
U$2: SOLDER_PAD-2.0; SOLDER_PAD_2.0
U$12: PAD_2.0
U$17: CC-NC-BCNIX; CC-NC-B_NIX
U$24: CHRG_LED; SOLDER_PAD_1.3
U$25: DONE_LED; SOLDER_PAD_1.3
U$41: PAD_1.25

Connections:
CHRG_LED: D2.A, D2E.A, J4.EXT-CHRG, R5.1, U$24.P$1
DONE_LED: D1.A, D1E.A, J4.EXT-DONE, R6.1, U$25.P$1
GND: C1.1, C2.1, C3.1, C4.1, C5.1, D1E.C, D2E.C, GBP_JACK.GND1 (GND), GBP_JACK.GND2 (GND), J1.A12-GND (GND), J1.B12-GND (GND), J2.2, J4.GND, R1.2, R2.2, R7.1, R10.1, R14.1, SJ1.1, U1.EPAD (GND), U$12.P$1
unnamed: D1.C, D2.C, SJ1.2
unnamed: J1.B5 (CC2), R1.1
unnamed: R8.2, U1.2 (TEST)
unnamed: D3E.A, J4.EXT-PWD, J4.EXT-PWD' (EXT-PWD)
unnamed: D3E.C, R14.2
unnamed: J1.A5 (CC1), R2.1
unnamed: C4.2, R9.1, U1.5 (BAT)
unnamed: C1.2, R3.1
unnamed: R5.2, U1.1 (D1)
unnamed: R7.2, U1.4 (NTC)
unnamed: R10.2, U1.6 (ICHG)
unnamed: R6.2, U1.3 (D2)
unnamed: L1.P$1 (1), U1.7 (SW)
V_BATT: C5.2, J2.1, L1.P$2 (2), R8.1, R9.2, U$1.P$1
V_USB: C2.2, C3.2, GBP_JACK.VCC, J1.A9-VBUS (VBUS), J1.B9-VBUS (VBUS), R3.2, U1.8 (VIN), U$41.P$1

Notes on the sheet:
GBP USB-C CHARGING KIT
https://giltesa.com
V2.0
(POWER ONLY)
USB
CHARGER
LIGHT BOARD
ISET=0.68A
GREEN
RED
VSET=NC

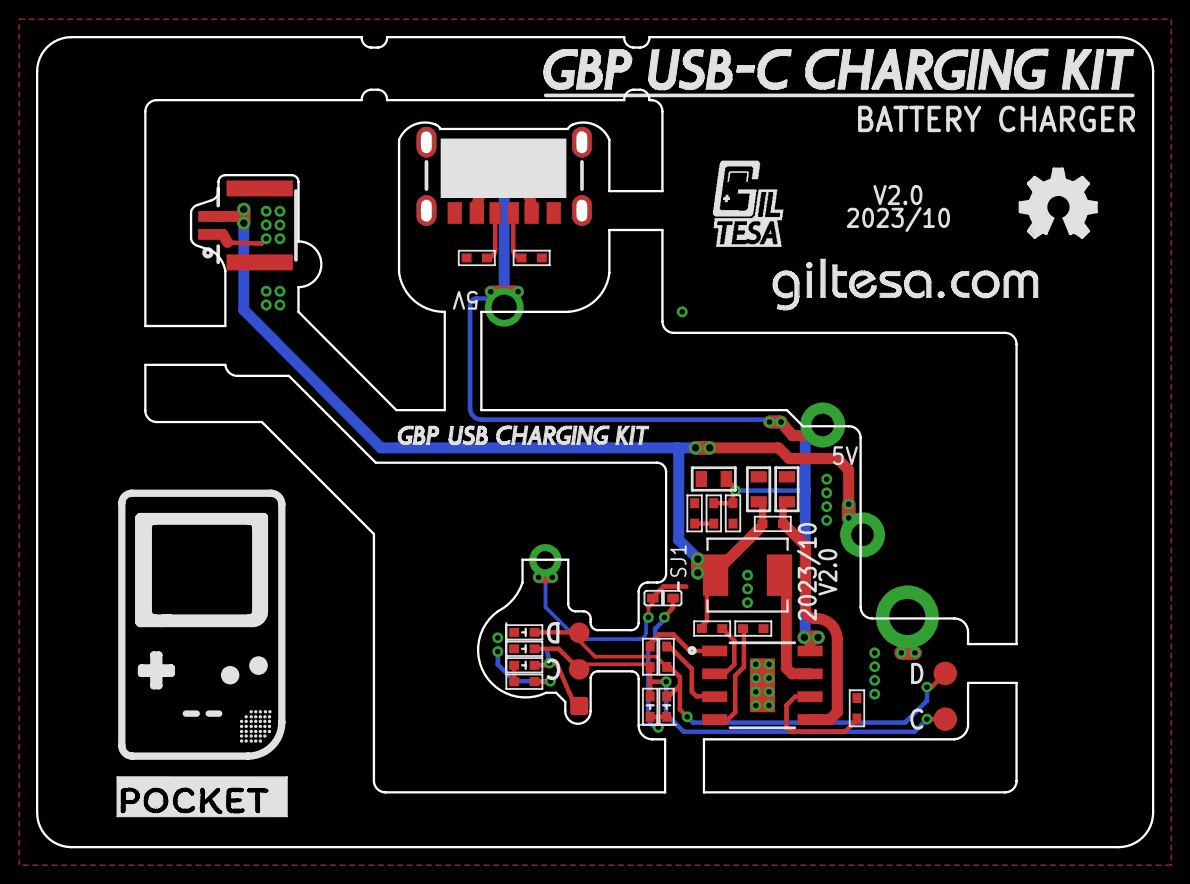
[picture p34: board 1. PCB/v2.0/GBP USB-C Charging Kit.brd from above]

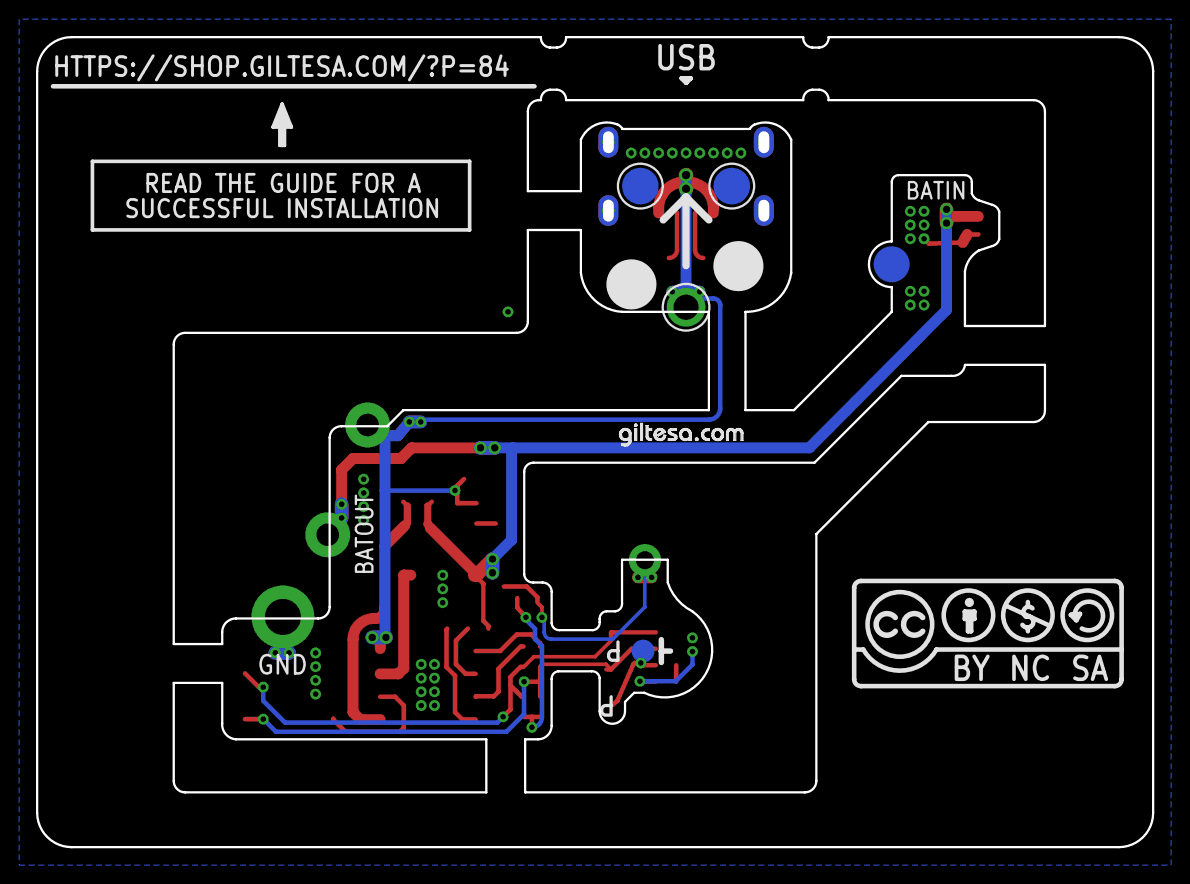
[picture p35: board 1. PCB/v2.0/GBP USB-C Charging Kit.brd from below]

Board: 2 copper layers, 62.0 x 45.0 mm, 42 parts (3 on the bottom side), 18 nets.

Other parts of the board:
LOGO1: OSHW_LOGO_FILLX0150-NT; OSHW_FILLX150_NOTEXT
U$3: CC-BY-NC-SA15MM; CC-BY-NC-SA_15MM
U$4: GBP_FRAME
U$7: GBP_FRAME_LOGO
U$10: GILTESA.COM_MASK
U$11: GAME_BOY_POCKET_USB_CHARGING_KIT_NON
U$13: GILTESA_LOGO_MASK_5MM
U$19: GILTESA.COM_MASK_7MM

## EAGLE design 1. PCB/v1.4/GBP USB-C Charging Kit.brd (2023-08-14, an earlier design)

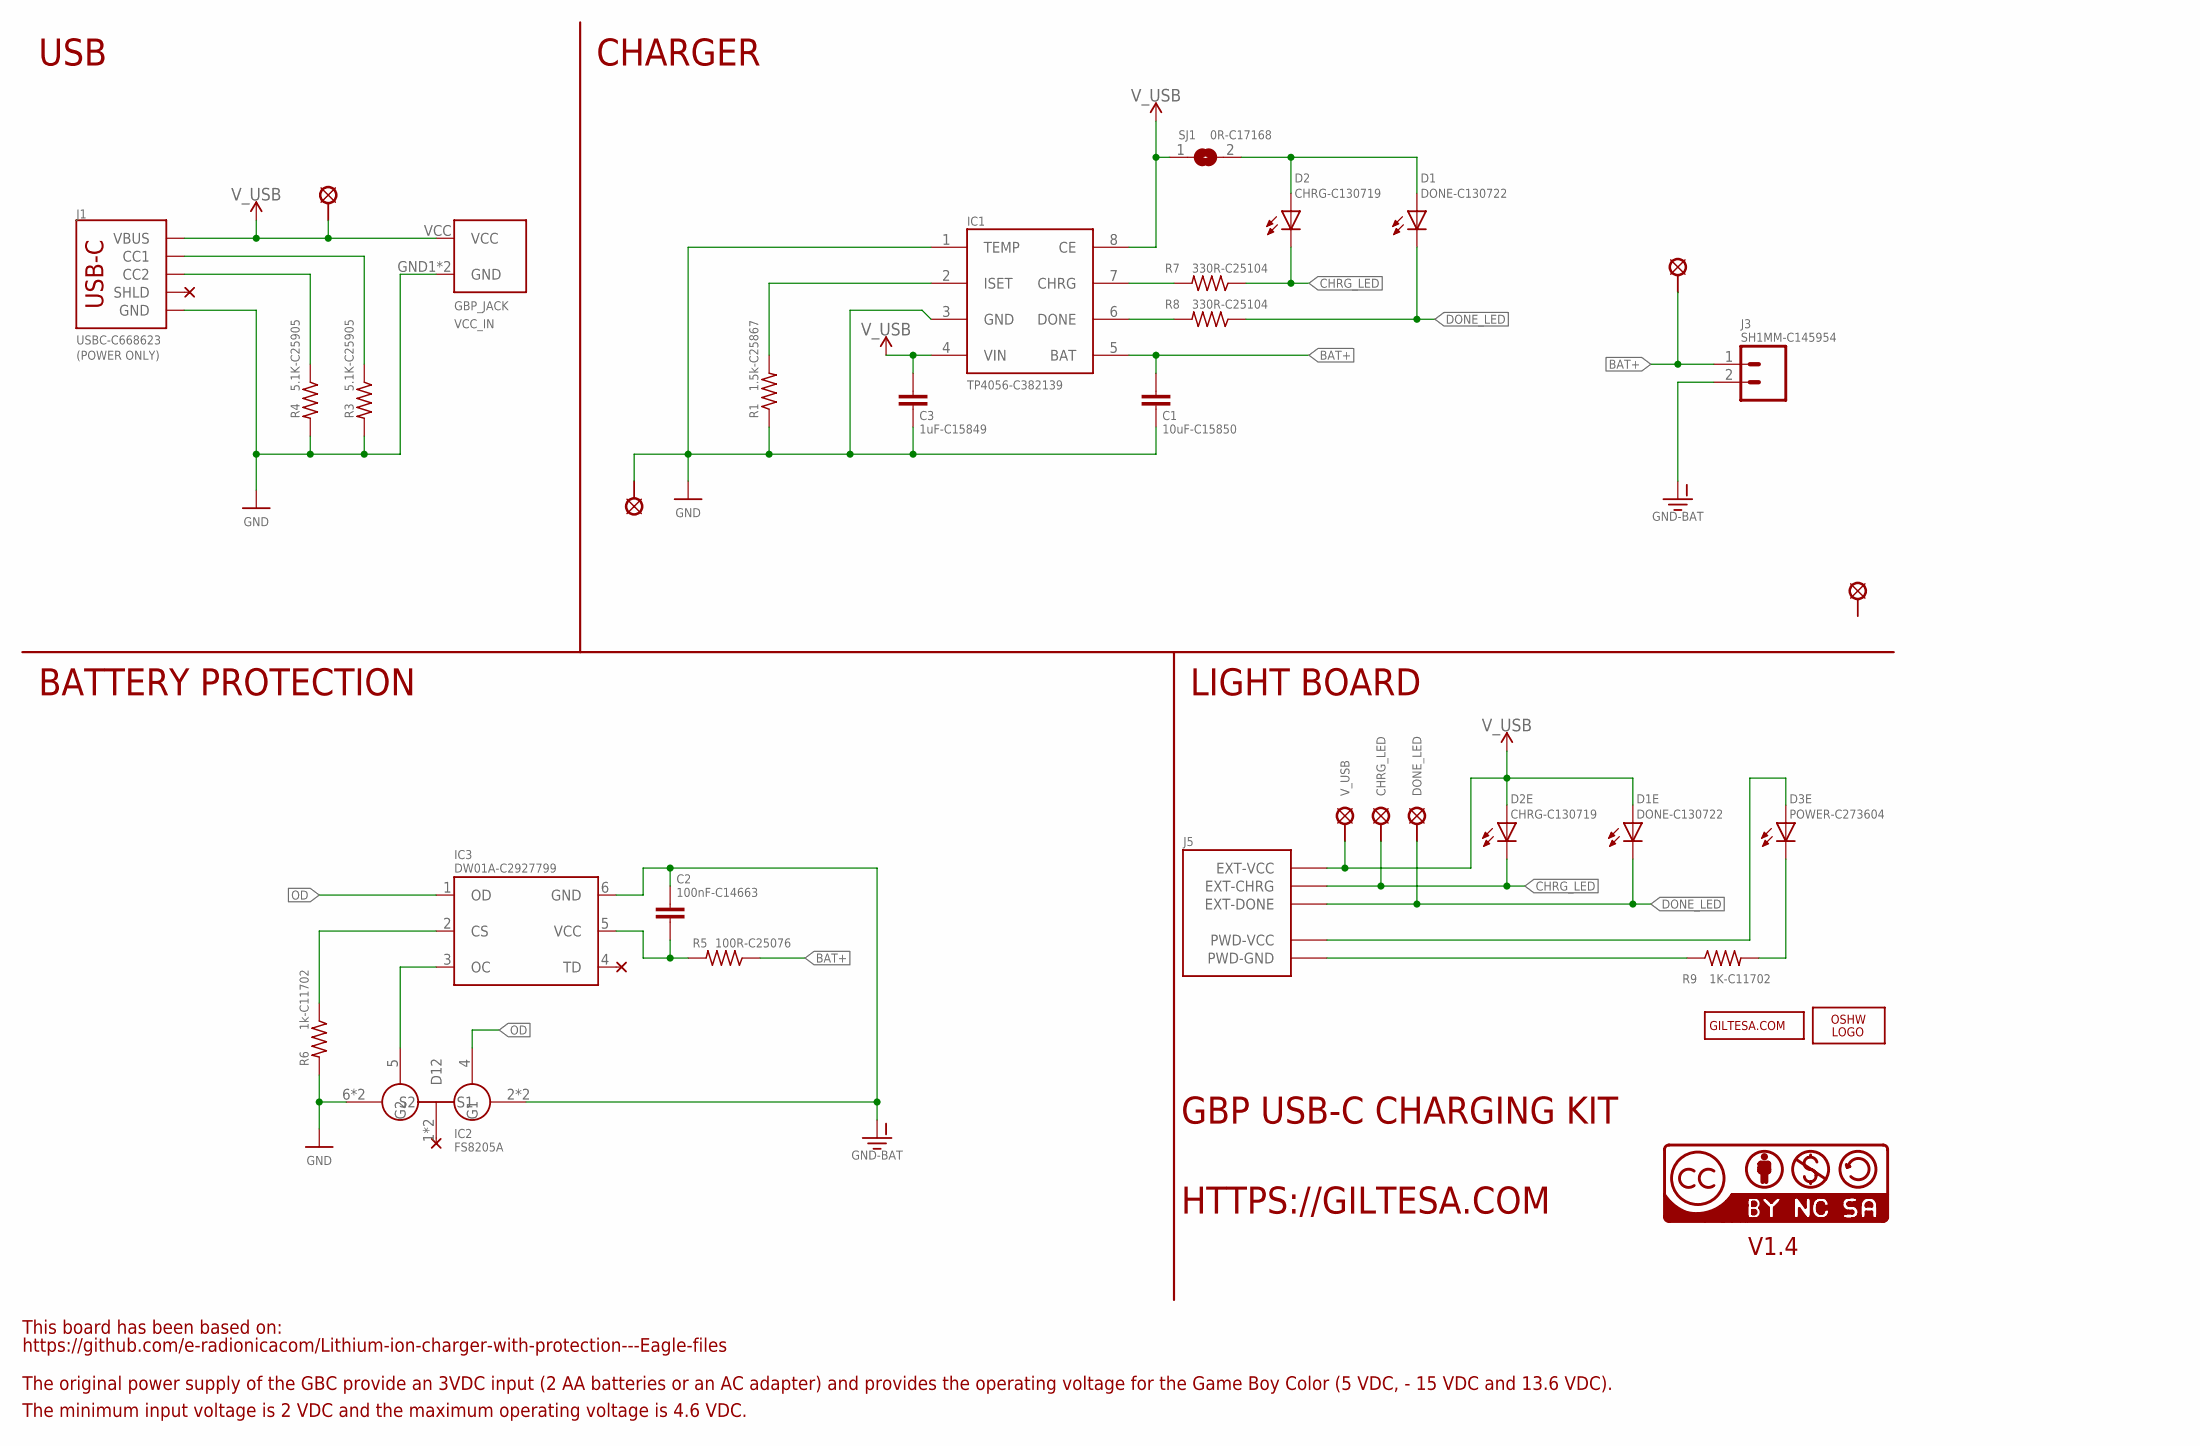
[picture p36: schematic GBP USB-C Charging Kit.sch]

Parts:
C1: 10uF-C15850; C0805_S
C2: 100nF-C14663; C0603_S
C3: 1uF-C15849; C0603_S
D1, D1E: DONE-C130722; L0402
D2, D2E: CHRG-C130719; L0402
D3E: POWER-C273604; L0402
GBP_JACK: VCC_IN; GBP_POWER_JACK_DIP
IC1: TP4056-C382139; SOIC-8
IC2: 8205A-C2929075; TSSOP8
IC3: DW01A-C2927799; SOT23-6L
J1: USBC-C668623; USB-C_6P
J3: SH1MM-C145954; JST-2-1MM-SMD_RIGHT
J5: GBP_LED
LOGO2: OSHW_LOGO_FILLX0150-NT; OSHW_FILLX150_NOTEXT
R1: 1.5k-C25867; R0402
R3, R4: 5.1K-C25905; R0402
R5: 100R-C25076; R0402
R6: 1k-C11702; R0402
R7, R8: 330R-C25104; R0402
R9: 1K-C11702; R0402
SJ1: 0R-C17168; JUMPER-SMD_0402
U$2: PAD_2.0
U$3, U$41: PAD_1.25
U$6: CC-BY-NC-SA15MM; CC-BY-NC-SA_15MM
U$12: SOLDER_PAD-2.0; SOLDER_PAD_2.0
U$16: GILTESA.COM_MASK; GILTESA.COM_MASK_15MM
U$24: CHRG_LED; SOLDER_PAD_1.3
U$25: DONE_LED; SOLDER_PAD_1.3
U$26: V_USB; SOLDER_PAD_1.3

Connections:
BAT+: C1.1, IC1.5 (BAT), J3.1, R5.1, U$3.P$1
CHRG: IC1.7 (CHRG), R7.2
CHRG_LED: D2.C, D2E.C, J5.EXT-CHRG, R7.1, U$24.P$1
DONE: IC1.6 (DONE), R8.2
DONE_LED: D1.C, D1E.C, J5.EXT-DONE, R8.1, U$25.P$1
GND: C1.2, C3.2, GBP_JACK.GND1 (GND), GBP_JACK.GND2 (GND), IC1.1 (TEMP), IC1.3 (GND), IC2.6 (S2), IC2.7 (S2), J1.GND1 (GND), J1.GND2 (GND), R1.1, R3.2, R4.2, R6.2, U$2.P$1
GND-BAT: C2.1, IC2.2 (S1), IC2.3 (S1), IC3.6 (GND), J3.2
ISET: IC1.2 (ISET), R1.2
unnamed: IC3.2 (CS), R6.1
unnamed: IC2.5 (G2), IC3.3 (OC)
unnamed: J1.B5 (CC2), R4.1
unnamed: D1.A, D2.A, SJ1.2
unnamed: D3E.C, R9.2
unnamed: J1.A5 (CC1), R3.1
OD: IC2.4 (G1), IC3.1 (OD)
PWD-GND: J5.PWD-GND, J5.PWD-GND' (PWD-GND), R9.1
PWD-VCC: D3E.A, J5.PWD-VCC, J5.PWD-VCC' (PWD-VCC)
VCC-DW: C2.2, IC3.5 (VCC), R5.2
V_USB: C3.1, D1E.A, D2E.A, GBP_JACK.VCC, IC1.4 (VIN), IC1.8 (CE), J1.VBUS1 (VBUS), J1.VBUS2 (VBUS), J5.EXT-VCC, SJ1.1, U$26.P$1, U$41.P$1

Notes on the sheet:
GBP USB-C CHARGING KIT
HTTPS://GILTESA.COM
V1.4
(POWER ONLY)
USB
CHARGER
BATTERY PROTECTION
LIGHT BOARD
IC2
FS8205A
https://github.com/e-radionicacom/Lithium-ion-charger-with-protection---Eagle-files
This board has been based on:
The original power supply of the GBC provide an 3VDC input (2 AA batteries or an AC adapter) and provides the operating voltage for the Game Boy Color (5 VDC, - 15 VDC and 13.6 VDC).
The minimum input voltage is 2 VDC and the maximum operating voltage is 4.6 VDC.

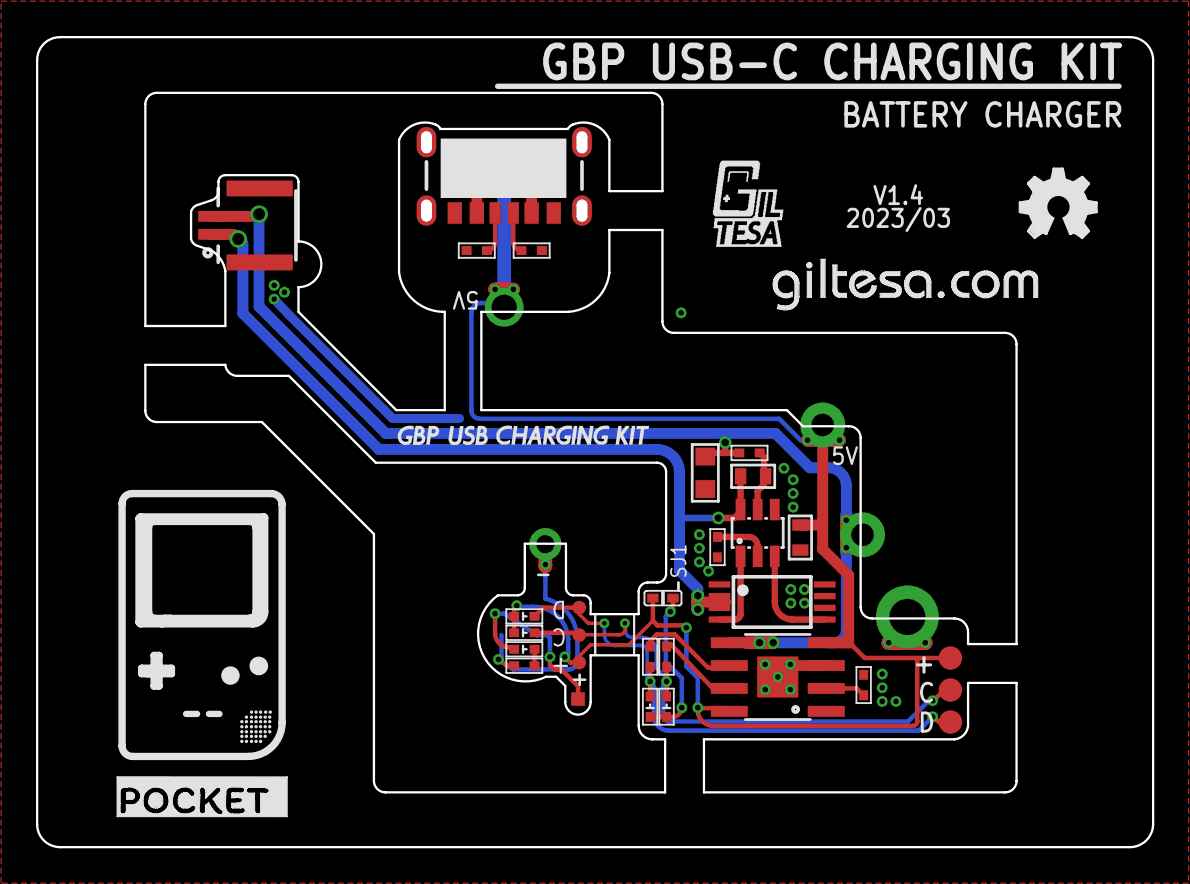
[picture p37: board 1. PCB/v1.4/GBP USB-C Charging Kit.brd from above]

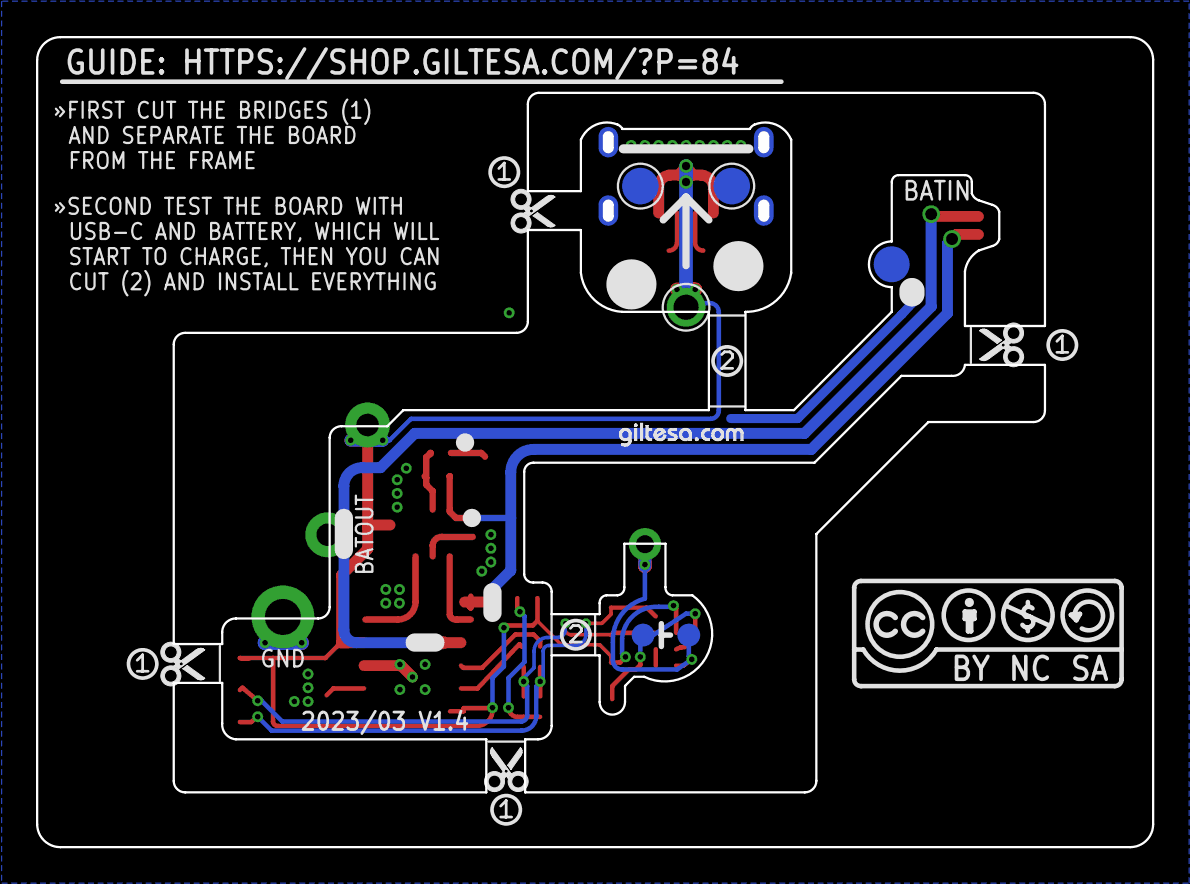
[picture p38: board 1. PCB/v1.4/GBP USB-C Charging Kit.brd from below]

Board: 2 copper layers, 62.0 x 45.0 mm, 51 parts (13 on the bottom side), 19 nets.

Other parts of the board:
U$1, U$8, U$9, U$10: SCISSOR_ONE
U$4: GAME_BOY_POCKET_USB_CHARGING_KIT_NON
U$7: GAME_BOY_POCKET
U$13: GILTESA_LOGO_MASK_5MM
U$14, U$18: SCISSOR_TWO
U$17, U$21, U$43, U$44: SCISSOR
U$19: GILTESA.COM_MASK_7MM@1
U$28: GAME_BOY_POCKET_2
U$37, U$38: CC-NC-BCNIX; CC-NC-B_NIX

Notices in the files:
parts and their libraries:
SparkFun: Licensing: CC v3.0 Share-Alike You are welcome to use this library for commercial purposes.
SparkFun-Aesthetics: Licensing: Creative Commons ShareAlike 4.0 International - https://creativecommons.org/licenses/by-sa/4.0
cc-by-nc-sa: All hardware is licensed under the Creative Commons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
